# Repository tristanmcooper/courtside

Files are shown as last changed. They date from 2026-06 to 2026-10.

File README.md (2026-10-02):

# Courtside — Multi-Modal Beach Volleyball Performance Sensing

> An end-to-end personal-analytics instrument that fuses a custom ESP32 courtside
> sensor node, wearable recovery data, and per-session self-report to explain
> day-to-day beach volleyball performance for a single athlete.

**Live demo → https://courtside-yr2r.onrender.com**
*(free tier — the first load cold-starts in ~30–60s; the people/relationships shown are synthetic demo data.)*

**📄 Full write-up → [Courtside_Final_Report.pdf](Courtside_Final_Report.pdf)**

Built solo for **ECE 284 — Hardware Sensing for Digital Health**, UC San Diego.

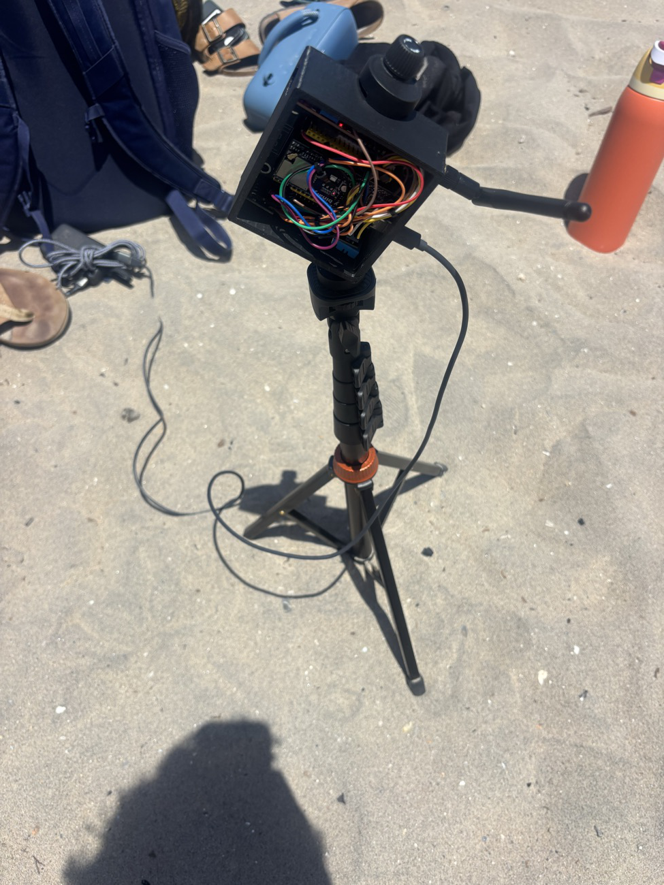
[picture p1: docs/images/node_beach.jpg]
Courtside node on the beach


## What it does

Three independent streams are captured courtside and time-aligned into one
per-session feature table:

- **Courtside node (hardware).** An ESP32-S3 logs air temperature + humidity
  (DHT11), sand-surface temperature (MLX90614 IR), and an acoustic wind proxy
  (electret mic). It posts readings over the athlete's iPhone hotspot to the
  cloud — no laptop needed on the sand.
- **Web app (FastAPI + Postgres).** A live phone dashboard for positioning the
  node, automatic ingestion of Apple Watch recovery metrics (HRV, resting HR,
  sleep) via Health Auto Export, a one-tap session log, and per-person /
  per-court / partner-vs-opponent relationship views.
- **Analysis (ML).** Per-session features → correlation screen → Lasso with
  leave-one-out CV → random forest / gradient boosting → SHAP, producing an
  interpretable ranking of which factors most explain performance.

## Screenshots

| Record a session | People & relationships |
|---|---|
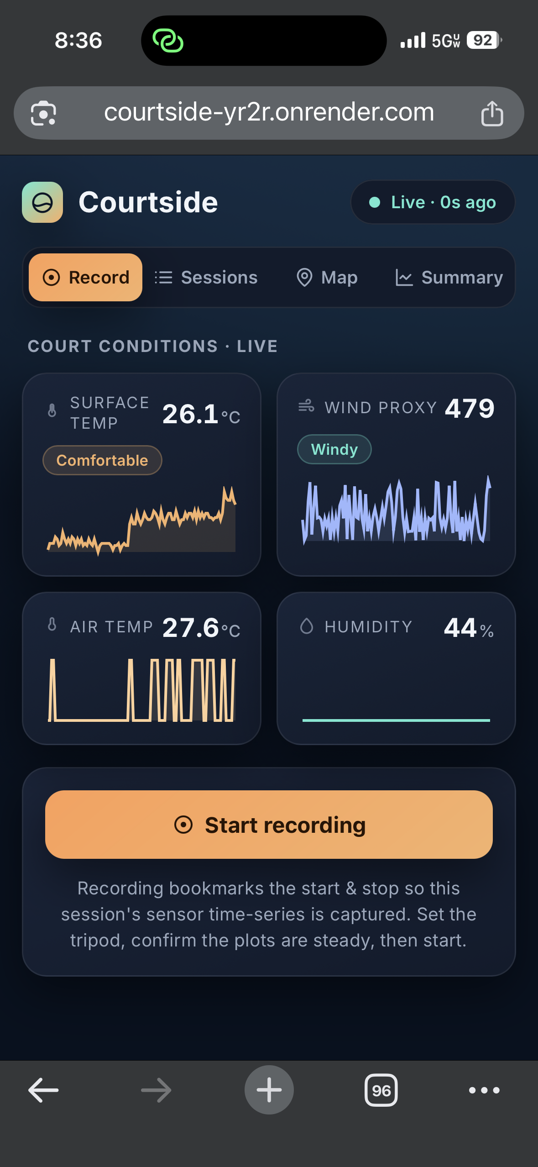
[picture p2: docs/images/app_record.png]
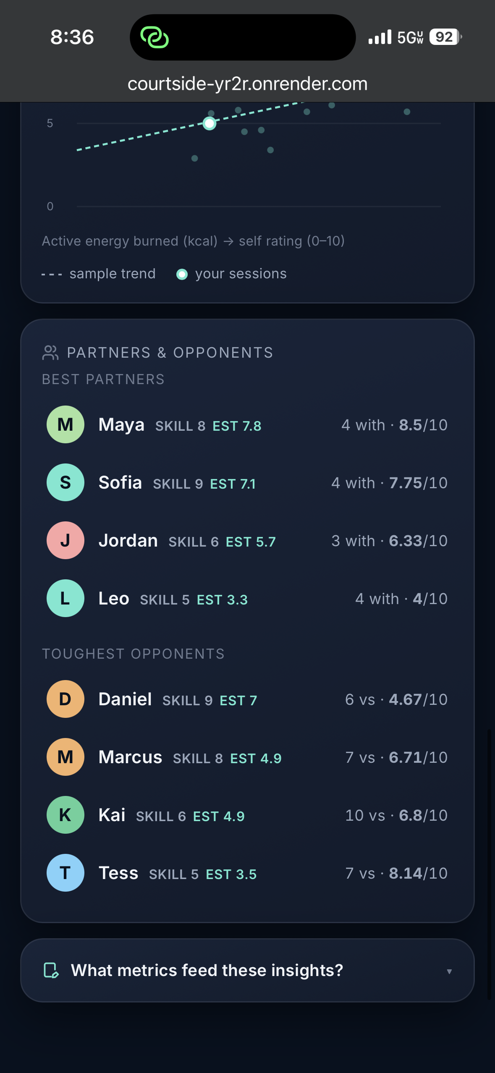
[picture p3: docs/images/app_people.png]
|  |  |
| **Court map** | **Recovery** |
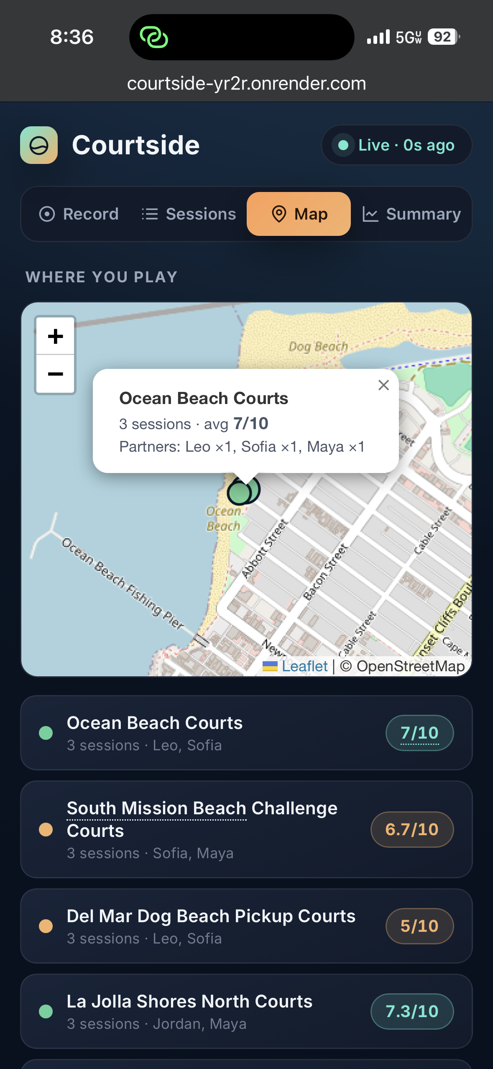
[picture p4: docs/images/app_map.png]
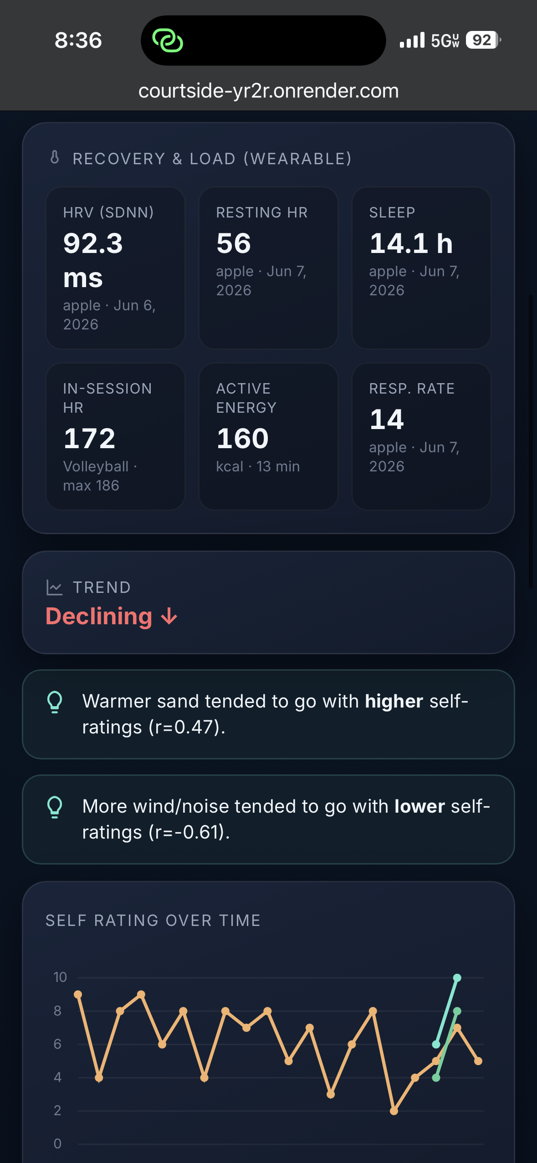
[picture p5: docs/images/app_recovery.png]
|  |  |

## Architecture

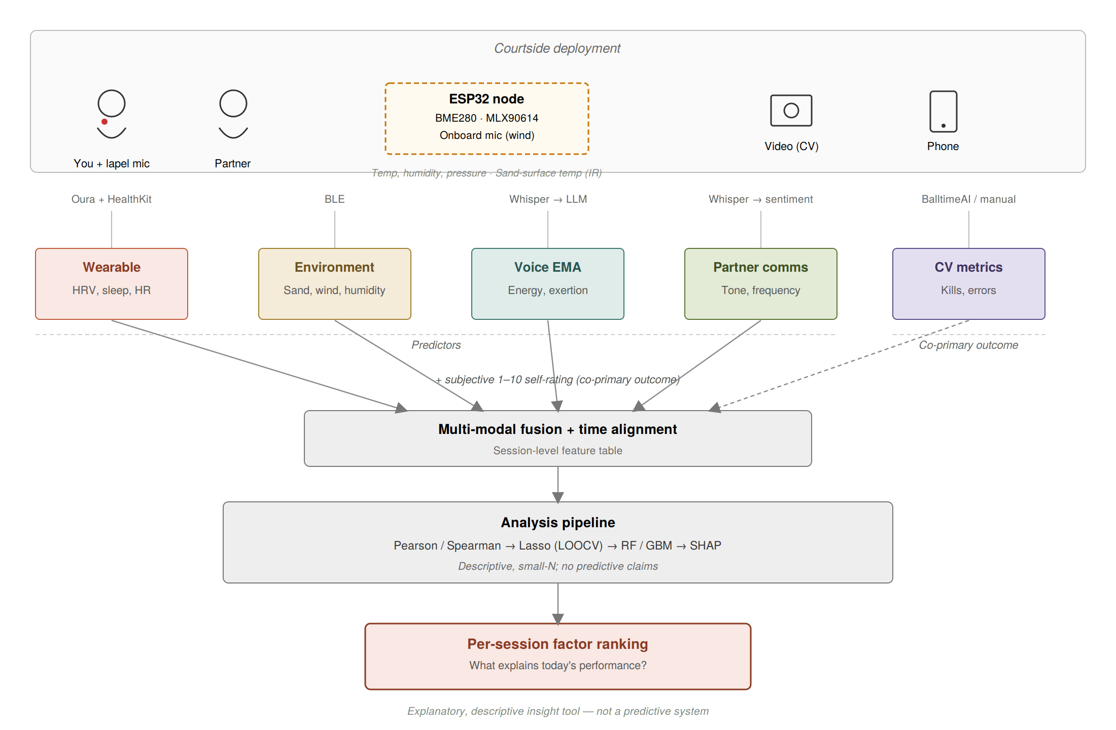
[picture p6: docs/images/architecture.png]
System architecture


## Factor ranking — the deliverable

The four-stage pipeline outputs an interpretable ranking of the environmental and
physiological factors that best explain session-to-session performance.

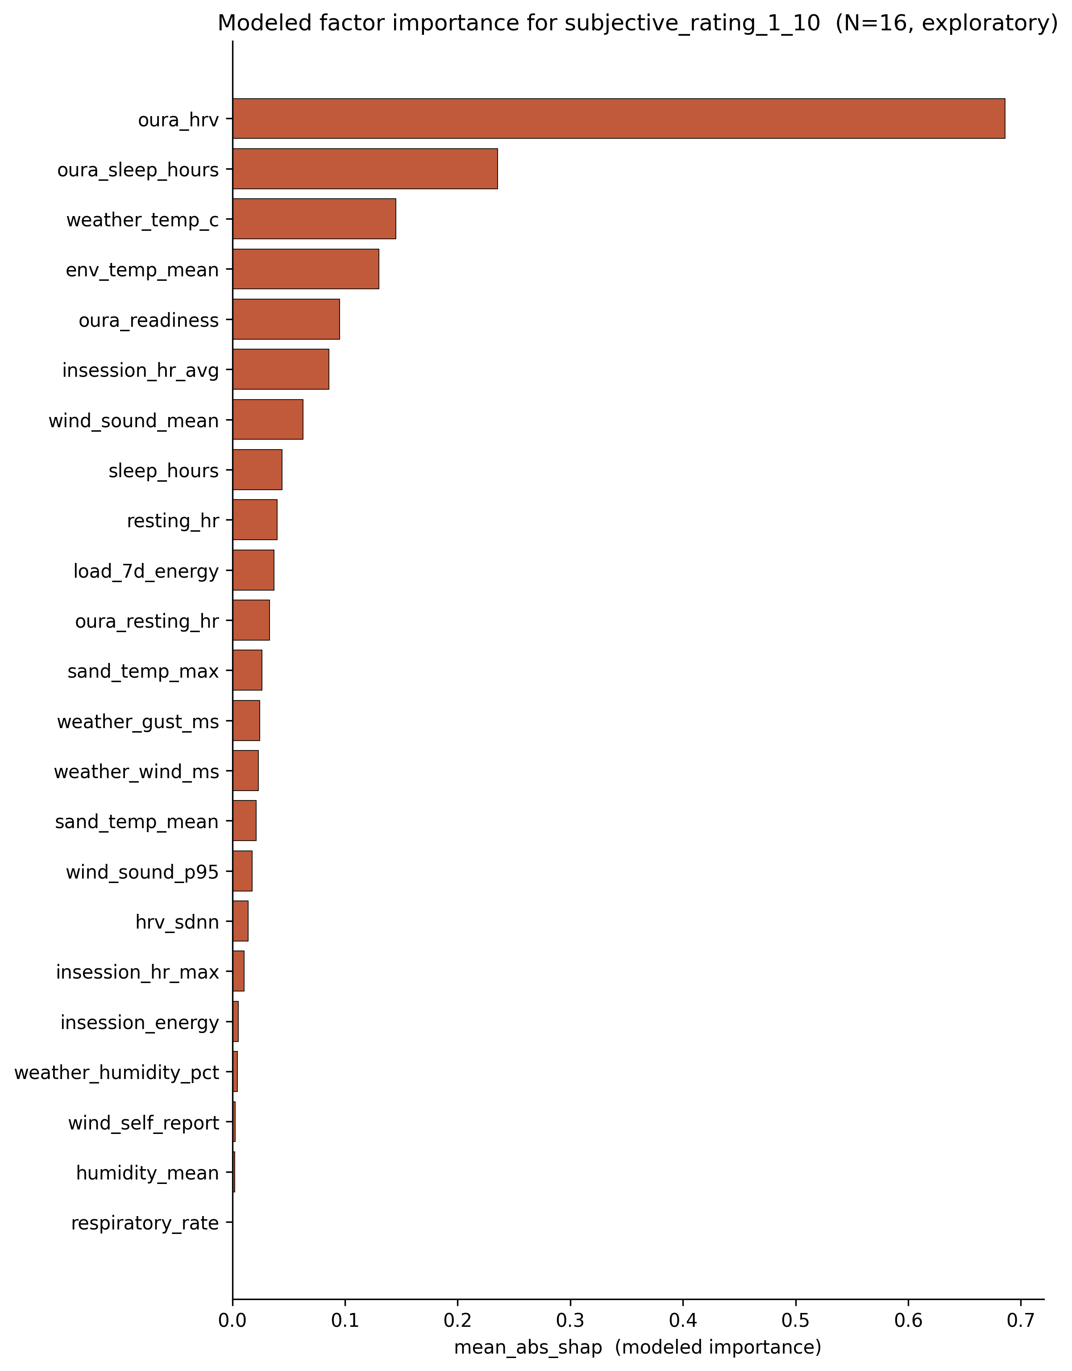
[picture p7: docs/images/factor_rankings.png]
Factor rankings


## Repo layout

```
firmware/   ESP32-S3 PlatformIO project (DHT11 + MLX90614 + mic, WiFi POST)
backend/    FastAPI app + mobile dashboard (one-click deploy via render.yaml)
scripts/    data pipeline: wearable parse, feature merge, 4-stage analysis
oura/       Oura API pull + validation plots
docs/       enclosure spec, HealthKit setup, run/defense guides, images
```

## Run it locally

```bash
# backend + dashboard
pip install -r backend/requirements.txt
uvicorn app.main:app --app-dir backend --reload        # http://127.0.0.1:8000

# firmware (PlatformIO)
cp firmware/include/secrets.h.example firmware/include/secrets.h   # fill in WiFi + backend URL
cd firmware && pio run -t upload && pio device monitor -b 115200

# analysis
pip install -r requirements.txt
python scripts/build_features.py && python scripts/analysis.py
```

Secrets (`.env`, `firmware/include/secrets.h`) are gitignored — copy the matching
`.example` files and fill in your own. Deploy to the cloud with the included
`render.yaml` (Render Blueprint → provisions the web service + Postgres).

## Notes & scope

- **N = 1 pilot.** Results are descriptive, not statistically powered; small-N is
  handled with LOOCV + regularization and reported honestly.
- **Demo data is synthetic** (`scripts/seed_demo.py`) — the partners, opponents,
  and relationship signals in the live demo exist to exercise the UI, not to
  describe real people.
- **Privacy.** Raw personal biometrics are kept out of this repo by design;
  regional weather (Open-Meteo) is used only as a coarse baseline against the
  node's court-level microclimate measurements.

## License

[MIT](LICENSE)

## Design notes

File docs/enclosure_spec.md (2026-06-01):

# Courtside Node — Enclosure Spec (for CAD)

A 3D-printed housing for a beach-volleyball courtside sensor node. It mounts on a
camera/phone tripod and holds a microcontroller + 3 environmental sensors + a
WiFi antenna. Used outdoors on sand in direct sun.

---

## Components to enclose

| # | Part | Function | Nominal size (CONFIRM) | Notes for housing |
|---|---|---|---|---|
| 1 | ESP32-S3 dev board ("Lonely Binary Gold") | brain + WiFi | ~70 × 26 × 6 mm (board); headers add ~10 mm height | USB-C on one short end must be accessible |
| 2 | **DHT11** module (blue) | air temp / humidity | ~22 × 28 mm board, sensor ~12 × 6 mm | blue sensor face must see open air; vented + shaded |
| 3 | MLX90614 IR thermometer (GY-906) | sand surface temp | ~13 × 17 mm board; metal can ~9 mm Ø, ~6 mm tall | **needs an open hole aimed down at sand** |
| 4 | Electret mic module | sound / wind proxy | ~10–15 × 15–33 mm (measure) | needs a port + foam windscreen |
| 5 | External WiFi antenna | range | flexible adhesive strip *or* SMA rod + pigtail | mount on outer/upper wall, away from metal |
| 6 | (Power) USB-C power bank | power | external | NOT enclosed — connects by USB-C cable |

Wiring is currently jumper wires; assume a small protoboard (~50 × 70 mm) or the
breadboard will sit at the bottom of the housing. Leave room + cable slack.

---

## Functional requirements (priority order)

### 1. Tripod mount — MOST IMPORTANT
- The tripod (VIMOSE 66") uses a standard **1/4"-20 UNC** screw (the male stud).
- The housing **base needs a 1/4"-20 female socket** to screw down onto it.
- **Do not print bare threads — they strip.** Use a **brass heat-set threaded
  insert (1/4"-20)** or a captured/recessed 1/4"-20 hex nut in a boss.
- Base should be flat and stable; ~6–8 mm thread engagement depth.

### 2. IR sensor aimed at the sand (MLX90614)
- The IR sensor reads surface temp by *line of sight*. **Plastic blocks IR — there
  must be an OPEN hole in front of it (no window/lens).**
- Because the node sits up on a tripod, the IR must point **down and out toward the
  sand at an angle** (e.g., a port on a lower / angled face).
- Make it **aim-able**: mount the MLX on a small adjustable bracket (tilt) or give
  2–3 alternate mounting positions, so Tristan can point it at the sand patch.
- Standard MLX90614 sees a ~90° cone — keep that cone unobstructed.

### 3. Mic / wind port
- The mic is the node's **only** wind sensor (no anemometer), used as a *qualitative*
  acoustic wind proxy — so the **foam windscreen is important**: it cuts direct-gust
  clipping so the signal tracks turbulence instead of pegging.
- A small **side port with a foam windscreen** (also a sand/spray shield, lets air in).
- A mic is *not* aimed like a directional sensor — wind noise is turbulence over the
  port, so exposure + the foam shield matter more than orientation.
- If adjustability is wanted, mount the mic on a rotatable plug.
- (The proxy is validated in software against self-reported wind + an Open-Meteo
  regional reference, not against an onboard anemometer.)

### 4. Temp/humidity chamber — must be vented + shaded
- A sealed sunlit box reads **falsely hot/dry**. The temp/humidity sensor needs a
  **vented, shaded sub-chamber** (radiation-shield / "Stevenson screen" idea):
  louvered vents on a **shaded** face (e.g., underside), airflow but no direct sun.
- This is why the whole housing should be **light/white** colored.

### 5. WiFi antenna
- Mount on an **outer or upper wall, away from the board and other metal** (metal
  shadows WiFi).
- If **SMA rod**: a ~6.5 mm bulkhead hole for the SMA connector.
- If **flexible adhesive antenna**: a flat exterior patch to stick it + a small
  slot to route the thin coax (U.FL) out from the board.

### 6. USB-C access
- A side cutout (~12 × 8 mm, position TBD by board) aligned with the ESP32's USB-C
  port, for power (power bank) and re-flashing without opening the case.

### 7. Access + assembly
- A **removable lid** (snap-fit or 4 screws) to get at the electronics.
- Internal **screw bosses or a slotted rail** so sensors can be repositioned.
- Cable strain-relief for the antenna coax and USB cable.

---

## Material & environment
- **PETG or ASA**, *not PLA* — PLA sags in beach heat / direct sun. ASA is best for
  UV; PETG is fine and easier to print.
- **Light/white color** — reflects sun, keeps the temp sensor honest.
- Sand-resistant (not waterproof): vents face down, no large top openings.
- Keep it compact but leave ~10–15 mm clearance around the board for cables/heat.

---

## Summary for a quick start
A light-colored vented box that **screws onto a 1/4"-20 tripod stud**, with: an
**open downward-angled hole** for the IR (sand) sensor, a **foam-screened side
port** for the mic, a **louvered shaded vent** for the temp/humidity sensor, an
**antenna mount** on an outer wall, and a **USB-C cutout**. Removable lid, internal
adjustable sensor mounts. Print in PETG/ASA, white.

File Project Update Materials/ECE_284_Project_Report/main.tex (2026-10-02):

\documentclass[sigconf,nonacm]{acmart}

% ACM Large 2-column per ECE 284 spec. If acmart is unavailable, replace with
% \documentclass[10pt,twocolumn]{article} and delete the \affiliation/\email block.

\settopmatter{printacmref=false, printfolios=true}
\renewcommand\footnotetextcopyrightpermission[1]{}
\pagestyle{plain}

\usepackage{graphicx}
\usepackage{booktabs}
\usepackage{amssymb}   % \checkmark
\usepackage{tikz}      % labeled hardware callouts
\usepackage{hyperref}

\title{Courtside: A Deployed Multi-Modal Sensing Instrument for Contextualizing Beach Volleyball Performance}

\author{Tristan Cooper}
\affiliation{%
  \institution{UC San Diego}
  \city{La Jolla}
  \state{CA}
  \country{USA}
}
\email{tmcooper@ucsd.edu}

\begin{document}

\begin{abstract}
Beach volleyball athletes experience large day-to-day performance variability that no single tool explains: wearables report overnight recovery without same-day context, weather services miss court-level microclimate (wind in particular), and mid-match self-report is impractical. We designed, built, and \emph{deployed} \textbf{Courtside}, a multi-modal sensing instrument that fuses six streams---a custom courtside environmental node (ESP32-S3 with a DHT11 air temperature/humidity sensor, an MLX90614 infrared sand-surface thermometer, and an electret-microphone wind/audio proxy), wearable recovery physiology (Apple Watch via automated HealthKit export and Oura Ring via API), wearable workout intensity (in-session and prior-load), coarse regional weather (Open-Meteo), per-session subjective/objective performance logging, and the \emph{spatial} and \emph{relational} context of each session (which court, and which partners and opponents). The node streams over the athlete's phone hotspot to a cloud backend (FastAPI + PostgreSQL on Render) and a mobile web app that runs live setup, session recording, evaluation entry, an interactive court map, and partner/opponent ``personas'' with statistically-guarded relationship signals. A four-stage factor-ranking analysis (correlation $\rightarrow$ sparse linear selection $\rightarrow$ tree ensembles $\rightarrow$ SHAP) closes the loop. We validate the instrument end-to-end on a single-athlete pilot---including a 20-respondent player survey that shaped the feature set and a live beach day capturing sand-surface temperatures near 40\,$^\circ$C against $\sim$26\,$^\circ$C air, alongside synchronized Apple Watch recovery and in-session heart rate. We frame the contribution honestly: the value is the \emph{working instrument}, the user-needs study, and the gap it fills---not statistical claims, which the small real sample ($N{=}2$ fully-instrumented sessions) cannot support. Where analytics need scale, we demonstrate them on clearly-labeled sample data \emph{built around those two real sessions} to show the output the instrument produces.

\smallskip
\noindent\emph{Artifact.} The complete system---firmware, backend, web app, and analysis---is open-source at \url{https://github.com/tristanmcooper/courtside}, with a live demo at \url{https://courtside-yr2r.onrender.com}.
\end{abstract}

\maketitle

\begin{figure}[t]
    \centering
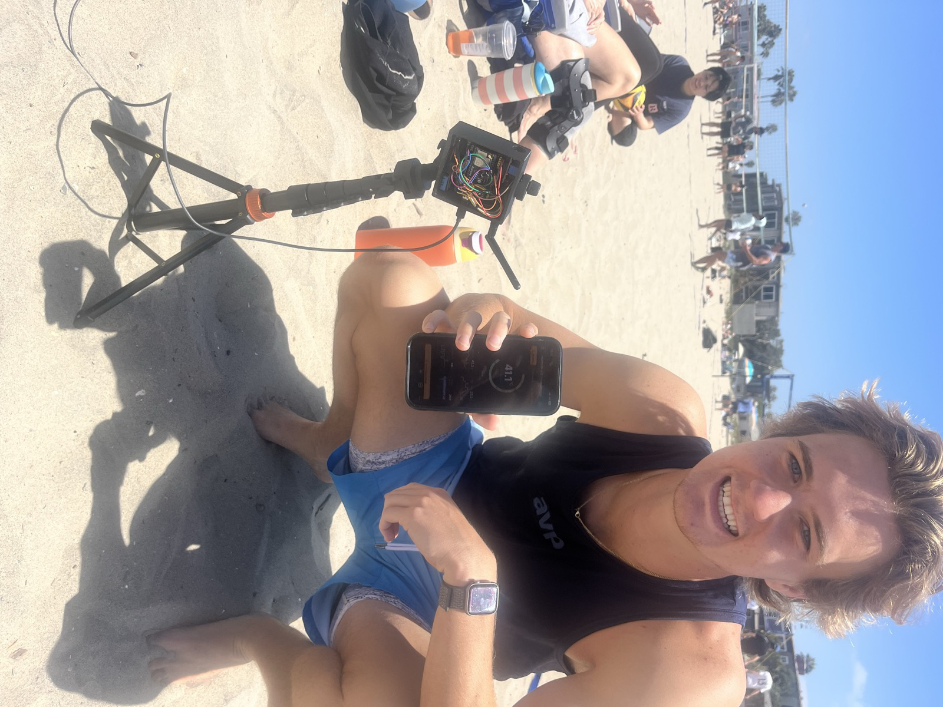
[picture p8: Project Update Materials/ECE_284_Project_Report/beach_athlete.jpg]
    
    \caption{The whole system in the field. The courtside node runs untethered on a tripod (battery-powered, streaming over the phone's hotspot); the athlete reads live conditions in the web app while an Apple Watch supplies recovery and in-session heart rate. Everything in this photo is a working part of the deployed instrument.}
    \label{fig:teaser}
\end{figure}

%===================================================================
\section{Motivation}
%===================================================================
I began this project from my own experience. After starting to play beach volleyball at an elite collegiate level, I found it genuinely hard to tell whether I was improving, to discriminate the quality of one training session from another, and to know \emph{what} actually drove a good or bad day. Playing with partners of all ages and skill levels, and across very different courts, made clear this is a common problem, not just mine: athletes know some days they play well and others they do not, but isolating \emph{why} is hard because recovery, environment, game context, and mindset all interact, while existing tools each measure one dimension in isolation---or none at all.

\textbf{Three blind spots.} \emph{(1) Wearables} (WHOOP, Oura, Garmin, Apple Watch) report readiness from overnight HRV and sleep but ignore same-day environmental load and subjective state. \emph{(2) Weather apps} report city-grid conditions and miss court-level microclimate: wind is reshaped by surrounding terrain---the Muir courts on the UCSD campus are ringed by buildings that create a swirling environment which reshapes serve-receive in a way no nearby weather station could capture---and sand-surface temperature varies with grain size, moisture, and direct sun in ways ambient air temperature cannot. \emph{(3) Self-evaluation} is limited to what an athlete can remember and to their own pattern recognition; it carries heavy confounds (partner, opponent) and places the entire measurement burden on the athlete mid-competition, when compliance collapses.

\textbf{The gap.} No system fuses \emph{recovery $+$ environment $+$ subjective state $+$ performance}---together with \emph{where} and \emph{with whom} a session happened---for an individual beach volleyball athlete. Each stream exists in isolation.

\textbf{Who benefits.} The immediate end user is the recreational or collegiate beach athlete who today has no way to contextualize why a session felt the way it did. The broader health relevance is exertional-heat safety: beach volleyball is outdoors with no climate control, and early warning for heat strain requires exactly the physiological--environmental--subjective fusion this instrument produces. A sand-surface temperature near 40\,$^\circ$C---measured in our pilot---is well above the $\sim$26\,$^\circ$C air temperature a weather app would report for the same moment.

%===================================================================
\section{Related Work}
%===================================================================
\textbf{Commercial wearable recovery.} WHOOP, Oura, and Garmin produce daily readiness scores from overnight biometrics; validation studies show reasonable resting HRV and sleep accuracy, but these scores are not contextualized against same-day environment or subjective state. Apple Watch exposes HRV (SDNN) and in-workout heart rate via HealthKit. Courtside treats these as one input among several rather than the whole picture.

\textbf{Environmental monitoring in sport.} The FIVB enforces WBGT-based heat protocols at professional events and the NATA publishes heat-illness position statements~\cite{casa2015}, but these rely on coarse point measurements and are largely absent from recreational and collegiate settings. We bring a low-cost court-level environmental node to exactly that gap.

\textbf{Ecological momentary assessment (EMA).} EMA is well-validated in sport and behavioral health~\cite{shiffman2008}; voice-based capture with modern ASR has been proposed to lower burden. We scope voice EMA out (Section~\ref{sec:discussion}) in favor of a low-burden structured post-session form.

\textbf{Wearables in beach volleyball.} Prior work targets different questions: Marzano-Felisatti et al.\ (2024)~\cite{marzano2024} applied an electronic performance-tracking system to quantify physical-conditional performance of young male players, and the University of Sussex ``Wearables in Beach Volleyball'' project~\cite{sussex} investigates IMU-based match load and event detection. Both focus on movement classification and training-load quantification from a single modality. Neither fuses physiological recovery, environmental context, spatial/relational context, and subjective experience into a joint per-session analysis.

\textbf{Gap.} No published system performs this multi-modal, individual-athlete fusion for beach volleyball.

%===================================================================
\section{Project Aim}
%===================================================================
\textbf{Primary aim.} Build a working instrument that captures synchronized multi-modal sessions for a single beach volleyball athlete and runs a per-session factor-ranking analysis identifying which contextual streams plausibly explain performance variation. \textbf{End user:} the athlete; output is personally actionable, not a clinical or coaching product. \textbf{Non-goals:} not a deployable predictive model, not cross-sport, not clinically validated.

\textbf{Following up on the proposal and update.} Table~\ref{tab:scope} maps what was proposed and updated against what was delivered, with honest substitutions. The proposal committed to Oura + Apple Watch + a BME280 environmental node + a subjective rating + 6--10 sessions, with voice EMA and computer-vision (CV) kill/error extraction as stretch goals. The update reported the survey, bench-validated sensing, and an MLX90614 in transit. For the final system, the environmental sensing, wearable ingestion, web app, and analysis pipeline were all delivered and deployed; the BME280 was substituted with a DHT11; the app additionally grew spatial (court map) and relational (partner/opponent personas) dimensions that were not in the proposal; and voice EMA and CV were de-scoped to keep the core instrument robust. The dominant gap versus the proposal is session count: collegiate season timing and hardware lead times compressed real data collection.

\begin{table}[t]
\caption{Proposed/updated vs.\ delivered. \checkmark\ delivered, $\sim$ substituted, $+$ added beyond proposal, $\times$ de-scoped.}
\label{tab:scope}
\small
\begin{tabular}{@{}lll@{}}
\toprule
Component & Proposed/Update & Final \\
\midrule
Wearable recovery (Oura) & API pull & \checkmark\ API \\
Wearable (Apple Watch) & HealthKit & \checkmark\ auto HealthKit export \\
In-session HR / workouts & stretch & \checkmark\ parsed (avg/max/energy) \\
Air temp / humidity & BME280 & $\sim$ DHT11 \\
Sand-surface temp (IR) & MLX90614 & \checkmark\ MLX90614 \\
Wind proxy (acoustic) & mic & \checkmark\ mic (qualitative) \\
Regional weather context & --- & $+$ Open-Meteo \\
Web app / live capture & local logging & \checkmark\ cloud app + recording \\
Court map (spatial) & --- & $+$ interactive map \\
Partner/opponent personas & --- & $+$ relational analytics \\
Subjective outcome & 1--10 rating & \checkmark\ rating (+ peer/coach) \\
4-stage analysis & planned & \checkmark\ implemented \\
Voice EMA & stretch & $\times$ de-scoped \\
CV kill/error outcome & stretch & $\times$ de-scoped \\
$\geq$6 full-stream sessions & target & $\times$ small $N$ (limitation) \\
\bottomrule
\end{tabular}
\end{table}

%===================================================================
\section{System Architecture and Implementation}
%===================================================================
The engineering is the heart of this project, so we describe the deployed system in detail. Figure~\ref{fig:arch} shows the end-to-end data path; it is a live system, not a mockup.

\begin{figure*}[t]
    \centering
    
    \caption{System architecture. The courtside node streams sensor readings over the athlete's phone hotspot to a cloud backend; the Apple Watch and Oura push recovery and workout data to the same backend; the athlete logs subjective/objective outcomes from the mobile web app. All streams are time-aligned into one per-session feature table feeding the four-stage factor-ranking analysis.}
    \label{fig:arch}
\end{figure*}

\subsection{Courtside Environmental Node}
An ESP32-S3 microcontroller (Fig.~\ref{fig:internal}) reads three channels at 1\,Hz: a \textbf{DHT11} (air temperature and humidity, one-wire digital); an \textbf{MLX90614} non-contact infrared thermometer (sand-surface temperature, I\textsuperscript{2}C address 0x5A) that senses emitted infrared and therefore requires no contact and no exposed window (plastic blocks infrared, so the enclosure leaves an open aperture aimed at the sand); and an analog \textbf{electret microphone} whose 50\,ms peak-to-peak amplitude serves as a low-cost wind/audio proxy. A deliberate hardware detail: the microphone is read on an \emph{ADC1} pin, because the ESP32's ADC2 is commandeered by the WiFi radio---reading the mic on ADC2 would silently fail whenever the radio is active.

The electronics are housed in a custom 3D-printed enclosure designed in Fusion~360 (Fig.~\ref{fig:cad}) with a louvered vent for the air sensor, an open IR aperture, a foam-screened microphone port, and a 1/4-20 thread so the node mounts on a standard camera tripod and can be raised, leveled, and rotated on site. The node runs untethered from a USB power bank. Figure~\ref{fig:internal} shows the internals: the printed lid (left) carries custom standoffs and cutouts that seat each sensor at its aperture, while the body (right) holds the board, the tripod boss, and the sensor harness.

\begin{figure}[t]
    \centering
    \begin{tikzpicture}
      \node[anchor=south west,inner sep=0] (img) at (0,0)
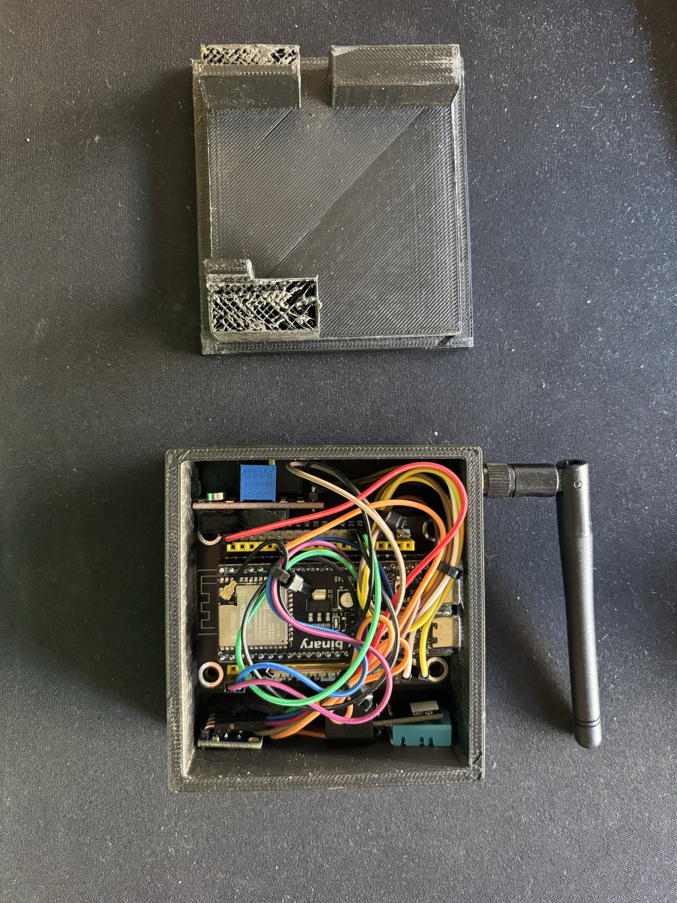
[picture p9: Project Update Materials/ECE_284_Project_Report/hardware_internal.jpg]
        {};
      \begin{scope}[x={(img.south east)},y={(img.north west)}]
        \tikzset{cal/.style={circle,fill=red!85!black,draw=white,line width=0.3pt,
          text=white,font=\scriptsize\bfseries,inner sep=0.7pt,minimum size=3.6mm}}
        \node[cal] at (0.64,0.90) {1};
        \node[cal] at (0.80,0.71) {2};
        \node[cal] at (0.865,0.61) {3};
        \node[cal] at (0.865,0.30) {4};
        \node[cal] at (0.52,0.30) {5};
        \node[cal] at (0.20,0.55) {6};
      \end{scope}
    \end{tikzpicture}
    \caption{Inside the node. \textbf{1} ESP32-S3 antenna; \textbf{2} USB-C power; \textbf{3} DHT11 air temperature/humidity (top-right); \textbf{4} MLX90614 infrared sand-surface sensor (bottom-right); \textbf{5} electret microphone wind/audio proxy (bottom-left); \textbf{6} 3D-printed lid with custom cutouts and standoffs that seat each sensor. (Callout positions per the build layout.)}
    \label{fig:internal}
\end{figure}

\begin{figure}[t]
    \centering
    \hfill
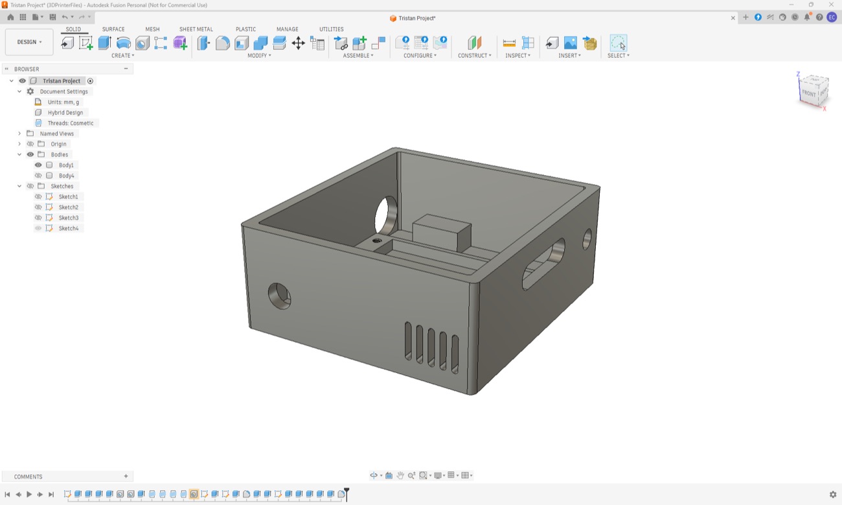
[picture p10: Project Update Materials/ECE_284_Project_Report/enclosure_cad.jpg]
    
    \caption{Left: the node deployed courtside on sand, tripod-mounted and battery-powered. Right: the enclosure CAD (Fusion~360)---louvered air-sensor vent, open IR aperture, and tripod mount.}
    \label{fig:cad}
\end{figure}

\subsection{Firmware and Connectivity}
The firmware (C++/Arduino, built in PlatformIO) connects to the athlete's iPhone Personal Hotspot as a WiFi station and HTTP-POSTs each reading as JSON to the backend, authenticated by a node key. It includes a boot-time I\textsuperscript{2}C bus scan that prints discovered addresses for field debugging, and a serial-CSV fallback so the node still logs if connectivity drops. Because the ESP32-S3 is 2.4\,GHz only, the hotspot is set to maximize-compatibility mode. This wireless-over-hotspot path is what lets the system run on a beach with no laptop and no SD card.

\subsection{Cloud Backend and Data Model}
A FastAPI service backed by PostgreSQL is deployed on Render and auto-deploys on each push. It exposes ingest endpoints (court readings, health, workouts), a session CRUD and recording API, people/personas, an aggregated court endpoint for the map, a relationship-signals endpoint, and a full export for the offline pipeline. The schema separates concerns into \texttt{court\_readings}, \texttt{health\_daily} (one row per day$\times$source), \texttt{sessions}, \texttt{workouts}, and---added for the relational features---\texttt{people} and a \texttt{session\_people} link table. Every wearable payload is retained losslessly in a raw JSON column so new signals can be promoted later without re-collection, and a lightweight auto-migration adds new model columns to the live database on deploy.

\subsection{Mobile Web App}
The app (vanilla JS, no build step, installable as a phone web app) is the instrument's user surface. Figure~\ref{fig:applive} shows it running live over cellular on the first instrumented beach day. It provides a \emph{live setup view} with real-time per-sensor plots and a heuristic check (it warns when the IR reading $\approx$ air temperature, indicating the sensor is not yet aimed at the sand); a \emph{recording} flow that bookmarks each session's start/stop so its sensor time-series window is captured; and an \emph{evaluation} form capturing the subjective 1--10 self-rating, optional peer/coach ratings, felt-wind, kills/errors, player state (energy, soreness, mental, warm-up, food timing), partner/opponents, location, notes, and geolocation.

\begin{figure*}[t]
    \centering
    \hfill
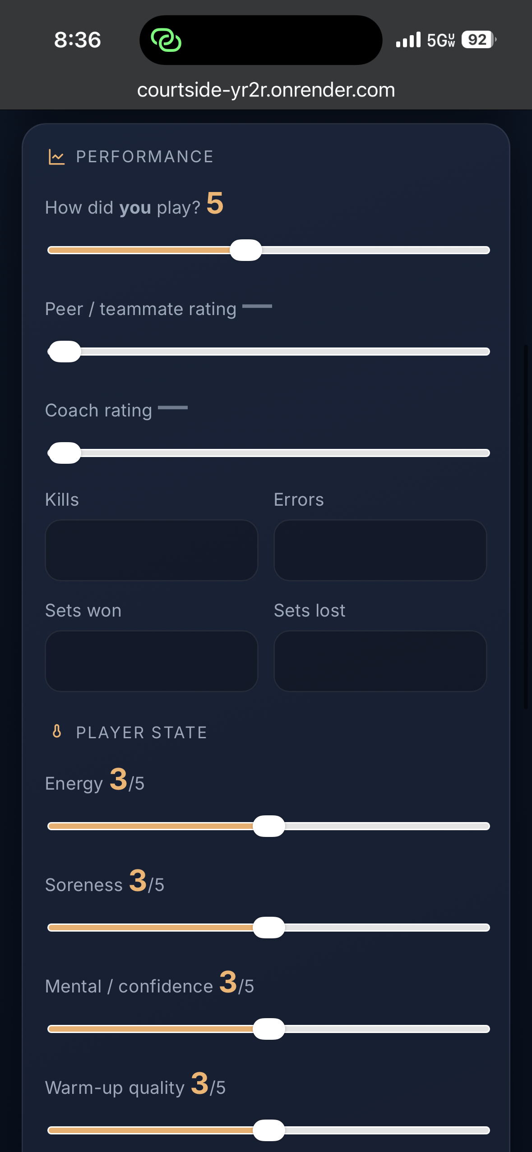
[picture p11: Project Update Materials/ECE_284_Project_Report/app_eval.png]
    \hfill
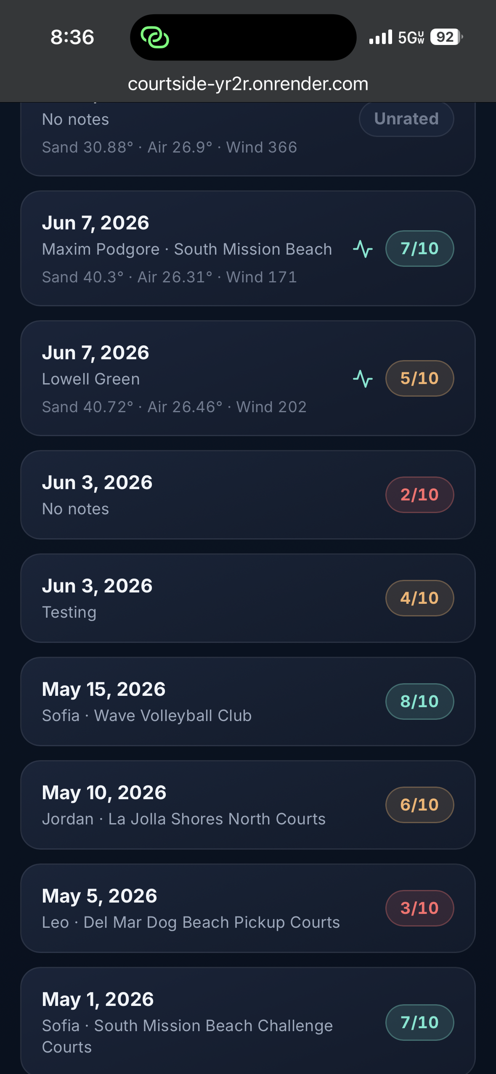
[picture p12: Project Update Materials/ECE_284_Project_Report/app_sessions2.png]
    
    \caption{The deployed app on the athlete's phone over 5G, with four tabs (Record, Sessions, Map, Summary). Left: the live setup view (``Live $\cdot$ 0s ago'') with balanced per-sensor cards and a ``Comfortable/Windy'' interpretation. Center: the post-session evaluation form, including the survey-driven player-state sliders (energy, soreness, mental, warm-up). Right: the session list---the June entries are \textbf{real pilot sessions} (sand 40.3--40.7\,$^\circ$C against $\sim$26\,$^\circ$C air, workout-paired), interleaved with sample sessions used for demonstration.}
    \label{fig:applive}
\end{figure*}

\subsection{Wearable and Weather Ingestion}
Apple Watch data syncs automatically via the Health Auto Export app's REST automation, posting HRV (SDNN), resting heart rate, sleep, respiratory rate, and \emph{workouts} to the backend, upserted by date. Oura is pulled via its v2 API as a \emph{second} recovery source, enabling cross-validation (Apple SDNN vs.\ Oura RMSSD). Open-Meteo~\cite{openmeteo} supplies coarse regional weather (wind, gust, temperature, humidity), kept clearly separate from on-court sensor readings---context, not mixed-in measurement.

\subsection{Spatial Context: the Court Map}
Because the app already captures geolocation, sessions are grouped by court and plotted on an interactive map (Fig.~\ref{fig:map}). Each marker is colored by the athlete's average rating there; tapping a court reveals its session count, average rating, average node-measured wind and surface temperature, and who the athlete has played with at that court. This makes ``I play better at La Jolla Shores than at Ocean Beach'' a queryable, visual fact rather than a vague impression.

\begin{figure}[t]
    \centering
    
    \caption{The Map view with a court tapped open: session count, average rating, and who the athlete has played with there, over markers colored by average rating. Populated mostly with \textbf{sample data} to demonstrate the feature; the pilot's real courts appear here too.}
    \label{fig:map}
\end{figure}

\subsection{Relational Context: Partner/Opponent Personas}
Beach volleyball is a 2v2 game and, candidly, a deeply relational and emotional one---who you play with and against shapes both performance and experience. Courtside therefore promotes partners and opponents from free text to first-class \emph{people} records that accrue history. For each person the app shows the athlete's average rating \emph{with} them (as partner) or \emph{against} them (as opponent), a self-rated skill, and an \emph{estimated} skill derived from results---a partner who consistently lifts the athlete's rating, or an opponent who consistently lowers it, reads as stronger (Fig.~\ref{fig:rel}, right).

Crucially, the app surfaces \emph{relationship signals} as notifications (Fig.~\ref{fig:rel}, left). For each person with enough sessions, it compares the athlete's ratings with versus without that person using a Welch's $t$-test (implemented in pure Python so the web service stays dependency-light), and flags notable, small-$N$-guarded effects: ``you play your best with Maya,'' or ``tough matchup against Daniel.'' This operationalizes the intuition every athlete has---``of course I played badly, I was up against the best player there''---into an explicit, evidence-weighted prompt. As with the pipeline, these analytics are shown on labeled sample data because the real pairing history is not yet large enough for inference.

\begin{figure*}[t]
    \centering
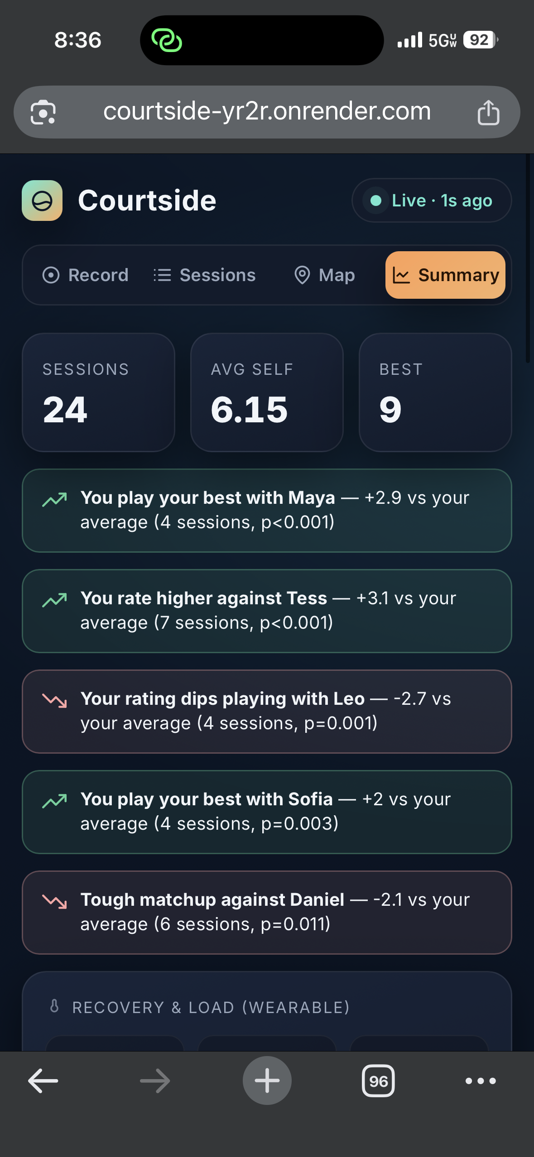
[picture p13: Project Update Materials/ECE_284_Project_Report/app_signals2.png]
    \hfill
    \hfill
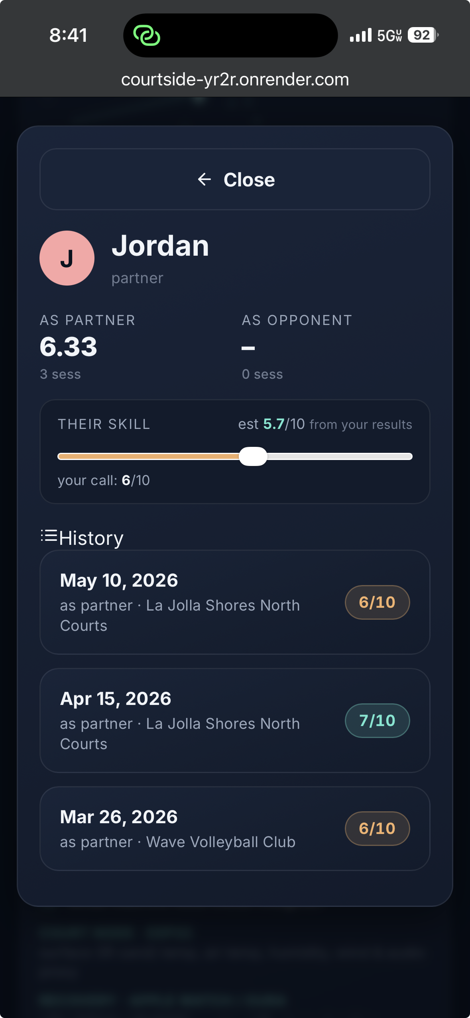
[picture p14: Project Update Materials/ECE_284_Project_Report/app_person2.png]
    
    \caption{Relational analytics (\textbf{sample data}; the pilot has only $N{=}2$ fully-instrumented real sessions, so these views are demonstrations built around the pilot's data). Left: relationship signals comparing the athlete's ratings with/without each person (Welch's $t$, small-$N$ guarded)---partner boosts and the ``tough matchup'' opponent drags. Center: partners and opponents ranked, each with a self-rated and a results-estimated skill. Right: a person view (a partner here) with as-partner/as-opponent averages and full history.}
    \label{fig:rel}
\end{figure*}

%===================================================================
\section{Design Decisions and Development History}
%===================================================================
The system arrived at its present form through a sequence of deliberate decisions; we recount them as a narrative (ordered, undated) because the \emph{reasoning} is the contribution.

\textbf{Survey before silicon.} Before investing further in hardware we ran a 20-player needs survey (Section~\ref{sec:results}) to decide what to sense. Wind ranking first is the reason the acoustic wind proxy survived and court noise and pace-of-play were dropped.

\textbf{Sensor selection and an honest substitution.} The proposal specified a BME280 (temperature, humidity, pressure). When the on-hand part proved unreliable, we substituted a DHT11 to keep air temperature and humidity working, accepting the loss of barometric pressure and lower resolution---a pragmatic trade we flag as a limitation rather than hide. The MLX90614 was chosen specifically because infrared sensing needs no ground contact and no fragile window.

\textbf{Bench-first bring-up.} Each sensor was validated on the bench before field use (Fig.~\ref{fig:bench}, Fig.~\ref{fig:smoke}), and the firmware gained an I\textsuperscript{2}C scanner so a missing sensor is diagnosable in seconds on the sand.

\textbf{The pivotal pivot: from scripts to a cloud instrument.} The original plan logged to a laptop over USB. We realized this is unusable on a beach, and re-architected around the athlete's phone: the node streams over the phone hotspot to a cloud backend, and the phone itself is the live dashboard. This single decision---no laptop, no SD card---is what makes the instrument genuinely field-usable.

\textbf{The app as the instrument, not an afterthought.} Once the data lived in the cloud, the web app became the product surface: live setup, recording windows, and evaluation entry replaced a clipboard and a spreadsheet.

\textbf{Frictionless wearable capture.} Rather than manual exports, we adopted Health Auto Export's REST automation so Apple Watch recovery and workouts arrive on their own, and kept Oura as an independent cross-check.

\textbf{Spatial and relational dimensions last.} With the core solid, we added the court map and the partner/opponent persona system---the features that most directly serve the ``relationship sport'' nature of beach volleyball---each backed by real database tables so they grow with use.

\subsection*{Fabrication}
The node was hand-built and hand-soldered (Fig.~\ref{fig:smoke}, left), with each subsystem brought up and smoke-tested individually before integration (Fig.~\ref{fig:smoke}, right shows the first working IR read).

\begin{figure}[t]
    \centering
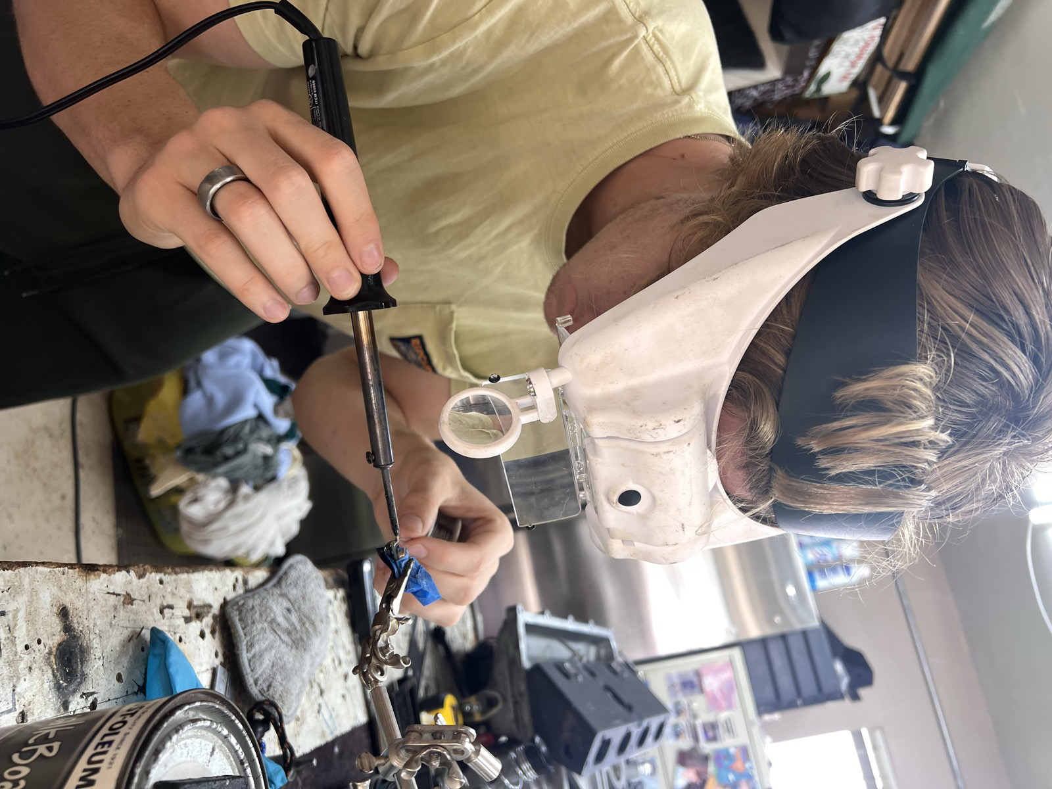
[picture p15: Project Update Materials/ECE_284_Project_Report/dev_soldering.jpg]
    \hfill
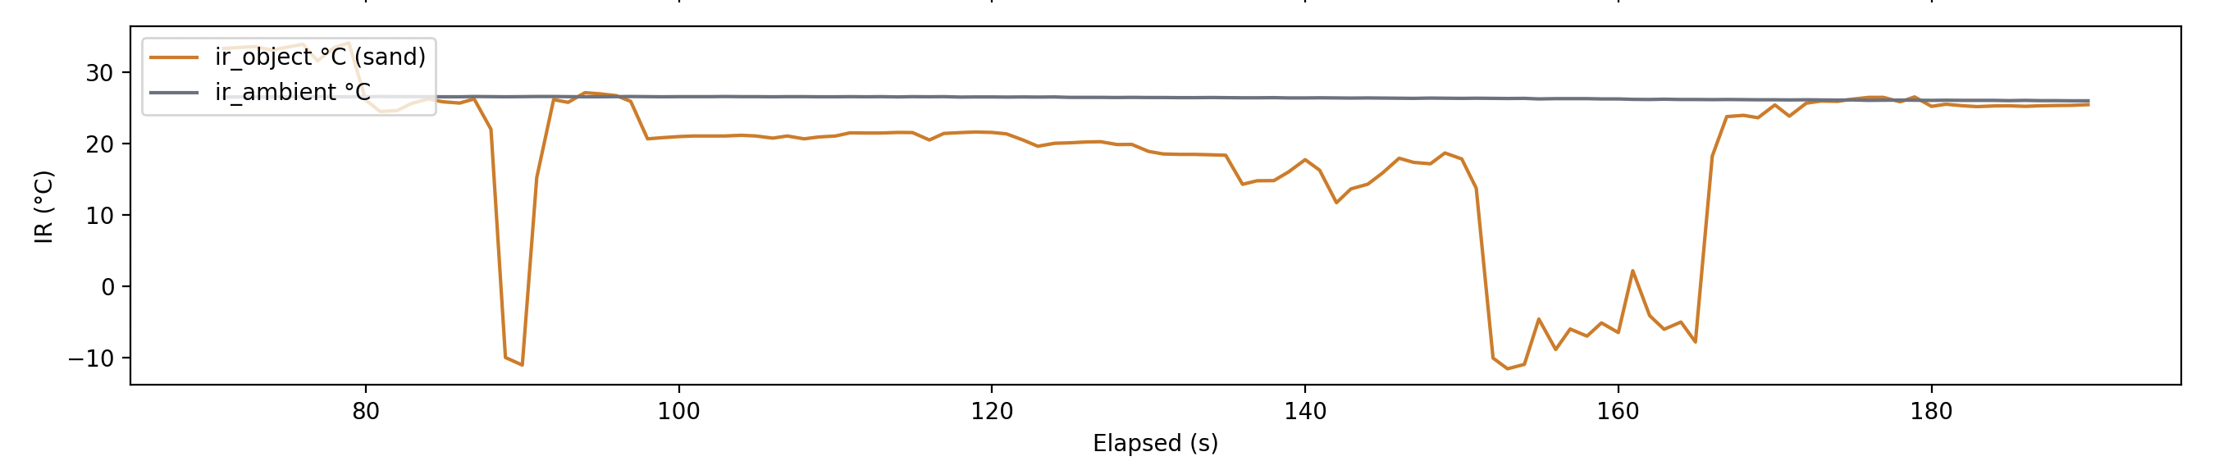
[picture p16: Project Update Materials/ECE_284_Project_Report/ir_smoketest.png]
    
    \caption{Fabrication and bring-up. Left: hand-soldering the node under a magnifier visor. Right: the first successful MLX90614 infrared read during bench bring-up.}
    \label{fig:smoke}
\end{figure}

%===================================================================
\section{Methodology}
%===================================================================
\subsection{Data Handling and Feature Engineering}
Sensor rows are stamped with server-receive time. Each logged session windows the node readings to its recording interval and aggregates them (mean/max sand and air temperature, mean humidity, mean and 95th-percentile wind-audio). Daily wearable recovery joins by date (Apple preferred, Oura fallback and cross-check). Apple Watch \emph{workouts} overlapping the session window yield in-session intensity (average/max HR, active energy); workouts in the prior seven days yield a cross-training \emph{load} feature. Regional weather is attached per session location, and partner/opponent links attach the relational context. The unit of analysis is the session---appropriate given small $N$---producing one tidy multi-modal feature row per session ($\sim$40 columns).

\subsection{Analysis Pipeline}
The analysis is exploratory and descriptive, in four small-$N$-aware stages: (1) Pearson and Spearman correlations of each feature against the subjective rating; (2) Lasso regression with leave-one-out cross-validation for sparse feature selection; (3) random-forest and gradient-boosting feature importances to capture interactions; (4) SHAP values~\cite{lundberg2017} from the gradient-boosting model for per-factor attribution. We additionally compute leave-one-session-out top-3 stability. The pipeline (scikit-learn~\cite{sklearn}) degrades gracefully: below a sample threshold it emits correlations plus an explicit caveat rather than fabricating a model. No $p$-values are reported as confirmatory, and no model is released for deployment.

\subsection{Relationship Statistics}
For the relational signals, each person's with-set and without-set of ratings are compared with a two-sided Welch's $t$-test (unequal variance), with the $p$-value computed from the regularized incomplete beta function in pure Python. Signals fire only with $\geq$3 sessions for the person, an effect of $\geq$0.8 rating points, and $p<0.1$---thresholds chosen to be informative on small samples while explicitly labeled preliminary.

\subsection{Evaluation Criteria}
Because the output is a per-session explanation rather than a prediction, standard ML metrics do not apply. We evaluate on engineering criteria: \textbf{data completeness} (fraction of sessions with all streams captured), \textbf{time alignment} (streams aligned to server-receive time and the recording window), \textbf{sensor responsiveness} (bench validation per channel), and \textbf{ranking stability / face validity} (leave-one-session-out stability and comparison of top factors to the athlete's recollection)---the latter two meaningful only once $N$ is sufficient.

%===================================================================
\section{Results}
\label{sec:results}
%===================================================================
\subsection{User-Need Validation (N=20)}
Before further hardware investment we surveyed 20 players (UCSD men's/women's beach teams plus recreational, club, NCAA, and Open/AVP players) to validate need and prioritize features (Fig.~\ref{fig:survey}). \textbf{Wind ranked first} (4.05/5), validating the decision to prioritize wind sensing; recovery/tiredness, mental state, partner identity, and partner communication completed the top five; court noise, location, and pace of play ranked lowest and were dropped from the feature plan. Open responses repeatedly raised \emph{food timing}, \emph{soreness}, and \emph{warm-up quality}, motivating the lightweight player-state inputs. Across the cohort, 85\% expressed positive interest, with qualified interest centered on wearable integration and minimal in-session burden.

\begin{figure}[t]
    \centering
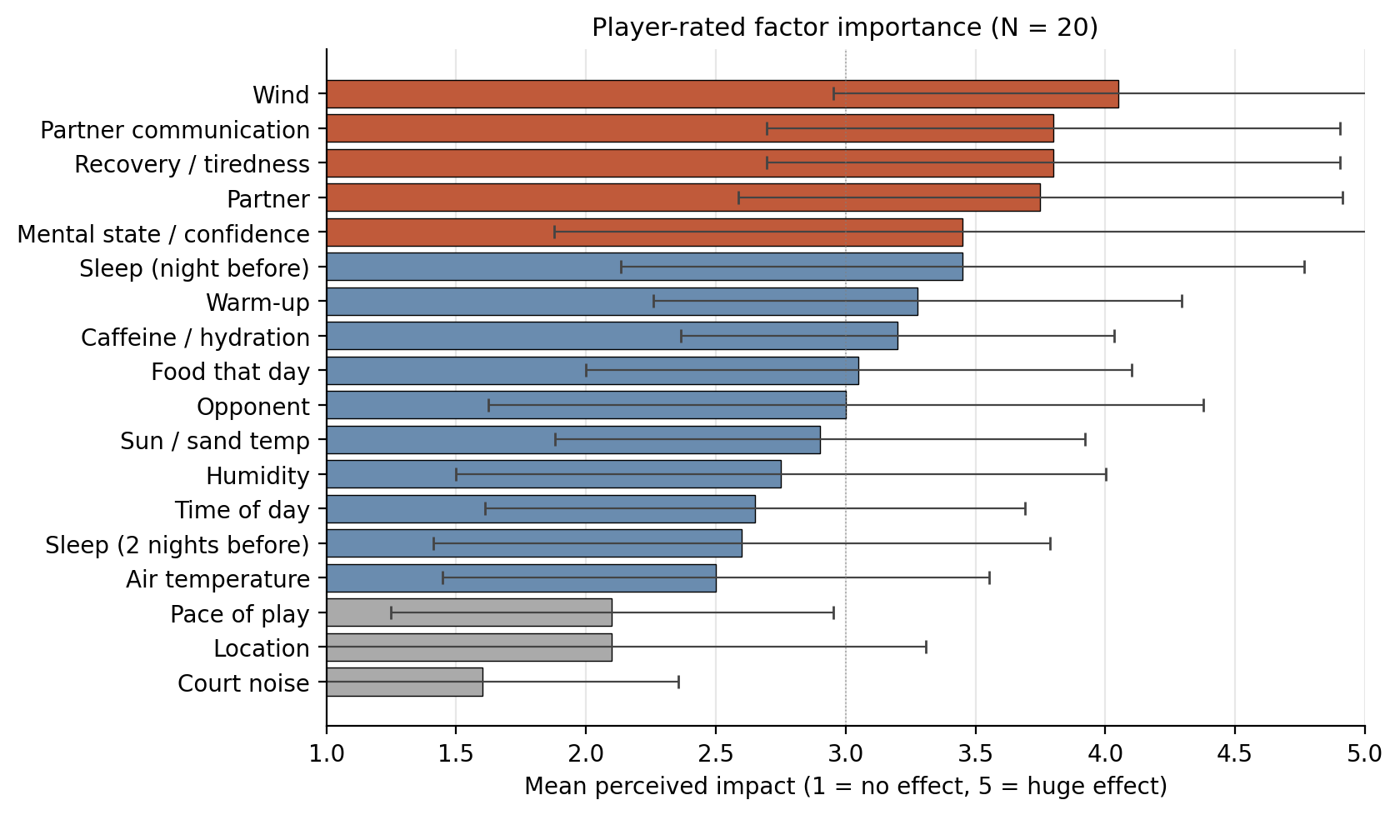
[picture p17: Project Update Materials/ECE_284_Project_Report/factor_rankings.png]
    
    \caption{Player-rated factor importance ($N=20$), mean $\pm$ 1 SD. Wind ranks first overall. Top five (orange) retained as primary engineered features; bottom three (gray) dropped.}
    \label{fig:survey}
\end{figure}

\subsection{Sensor Validation (Bench)}
Each channel was validated for responsiveness (Fig.~\ref{fig:bench}): exhaling on the node produces the expected coupled DHT11 temperature/humidity spike with exponential return to ambient; blowing across the microphone produces clear transient amplitude spikes above a stable baseline; and the MLX90614 tracks a warm surface in its field of view (an immediate $\sim$10\,$^\circ$C rise aimed at skin). The Oura API pipeline was separately validated against a 21-day rolling window (Fig.~\ref{fig:oura}).

\begin{figure}[t]
    \centering
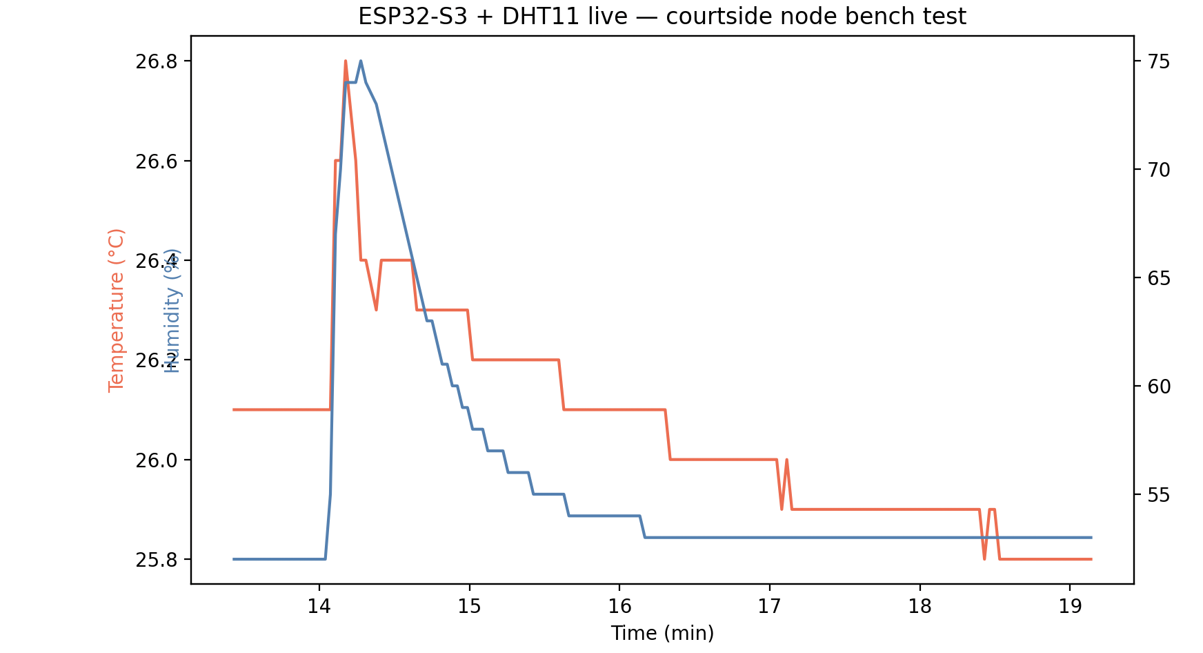
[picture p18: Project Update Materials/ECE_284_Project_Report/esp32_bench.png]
    \hfill
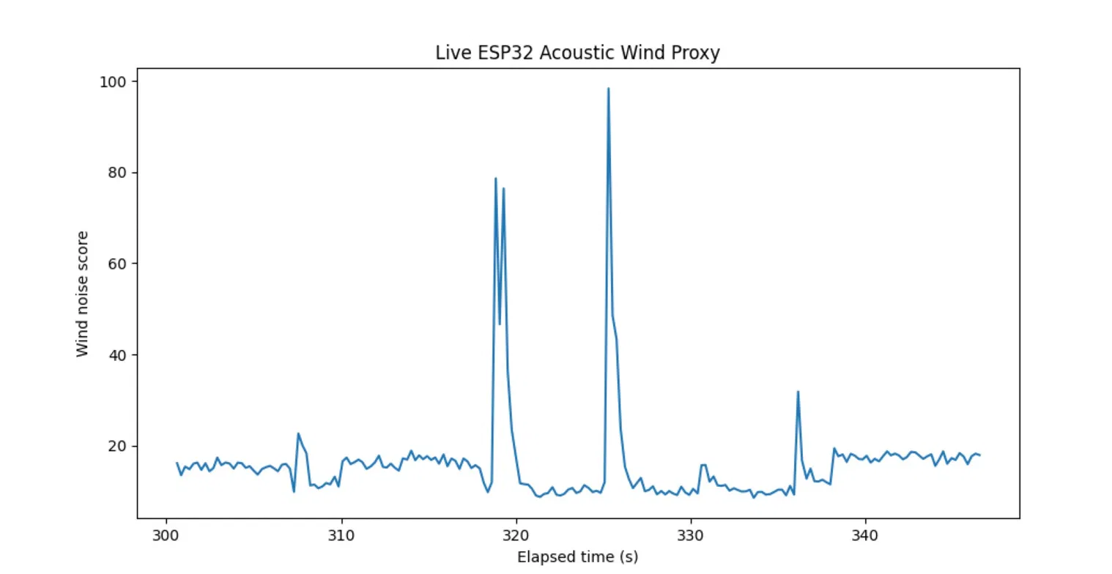
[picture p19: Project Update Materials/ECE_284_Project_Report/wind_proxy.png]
    
    \caption{Bench validation. Left: an exhalation event produces a coupled temperature/humidity response. Right: the acoustic wind proxy responds to blown-air transients above a stable baseline.}
    \label{fig:bench}
\end{figure}

\begin{figure}[t]
    \centering
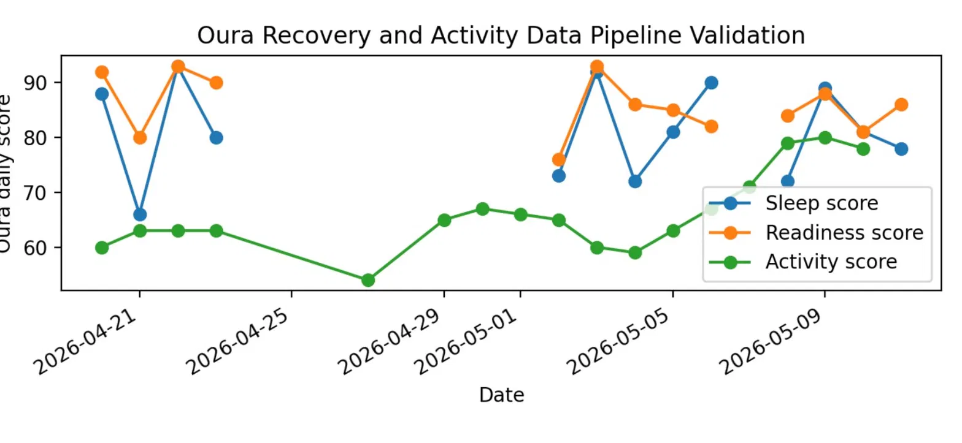
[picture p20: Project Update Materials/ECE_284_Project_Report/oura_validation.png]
    
    \caption{Oura recovery pipeline validated over a rolling multi-week window (HRV, resting HR, sleep), providing an independent cross-check on the Apple Watch recovery stream.}
    \label{fig:oura}
\end{figure}

\subsection{Live Courtside Pilot}
The full wireless path was exercised on the beach (Fig.~\ref{fig:teaser}, Fig.~\ref{fig:applive}): the node ran from a USB battery, joined the phone hotspot, and streamed to the cloud while the athlete used the live dashboard to position the tripod. On instrumented beach days we recorded real sessions with sand-surface temperatures of \textbf{40.3--40.7\,$^\circ$C} against $\sim$26\,$^\circ$C air---directly demonstrating the court-level microclimate that weather data cannot capture---tagged with real partners (e.g., a session at South Mission Beach) and real ratings. Apple Watch recovery for the same windows arrived automatically (HRV, resting HR, sleep), and Volleyball workouts were ingested with in-session heart rate (average 140--172\,bpm, peak up to $\sim$186\,bpm) and active energy (160--459\,kcal); Figure~\ref{fig:recovery} shows this real wearable data populated live in the app. The build step assembled a $\sim$40-column multi-modal feature row per session, confirming end-to-end fusion. In total, the pilot produced \textbf{two fully-instrumented sessions} carrying every stream simultaneously---enough to prove the fusion end-to-end, but not enough for inferential ranking.

\begin{figure}[t]
    \centering
    
    \caption{The Summary recovery panel with \textbf{real} pilot wearable data: HRV (SDNN), resting HR, sleep, the in-session heart rate from a timestamp-paired Volleyball workout (avg 172, max 186\,bpm), and active energy---flowing automatically from the Apple Watch into the deployed app.}
    \label{fig:recovery}
\end{figure}

\subsection{Pipeline Demonstration (Sample Data)}
Because the number of \emph{fully-instrumented} real sessions is currently too small for interpretable ranking---\textbf{only $N{=}2$ sessions to date carry every stream simultaneously}, and a correlation over a handful of points can exceed 0.8 by chance---we ran the unmodified pipeline on a clearly-labeled sample dataset of 16 sessions \emph{built around those two real sessions}: it matches their observed value ranges (e.g.\ $\sim$40\,$^\circ$C sand and the measured heart-rate and sleep ranges) and adds a planted plausible structure (better sleep/HRV and cooler, calmer conditions $\rightarrow$ higher rating). The pipeline recovers that structure (Fig.~\ref{fig:sim}): HRV correlates positively ($r\approx0.67$) and sand-surface temperature negatively ($r\approx-0.36$) with the rating, and the leave-one-session-out stability column flags which factors are robust. This demonstrates \emph{what the instrument produces at scale}, not a finding.

\begin{figure}[t]
    \centering
    
    \caption{Pipeline factor-ranking \emph{output} on a labeled \textbf{sample} 16-session dataset built around the pilot's $N{=}2$ real sessions (not real results). Demonstrates the end-to-end analysis and its self-reported stability; real-data ranking awaits sufficient $N$.}
    \label{fig:sim}
\end{figure}

The instrument also produces targeted, personally-actionable relationship views (Fig.~\ref{fig:demorel}). Pairing each Apple Watch workout to its node session window by \emph{timestamp overlap} yields \emph{actual effort} (in-session heart rate) alongside \emph{reported performance}; overnight \emph{sleep} can likewise be plotted against performance. On sample data, sleep tracks self-rated performance more strongly than raw physical effort---exactly the contrast the tool is designed to surface, and a reminder that more effort is not more performance.

\begin{figure}[t]
    \centering
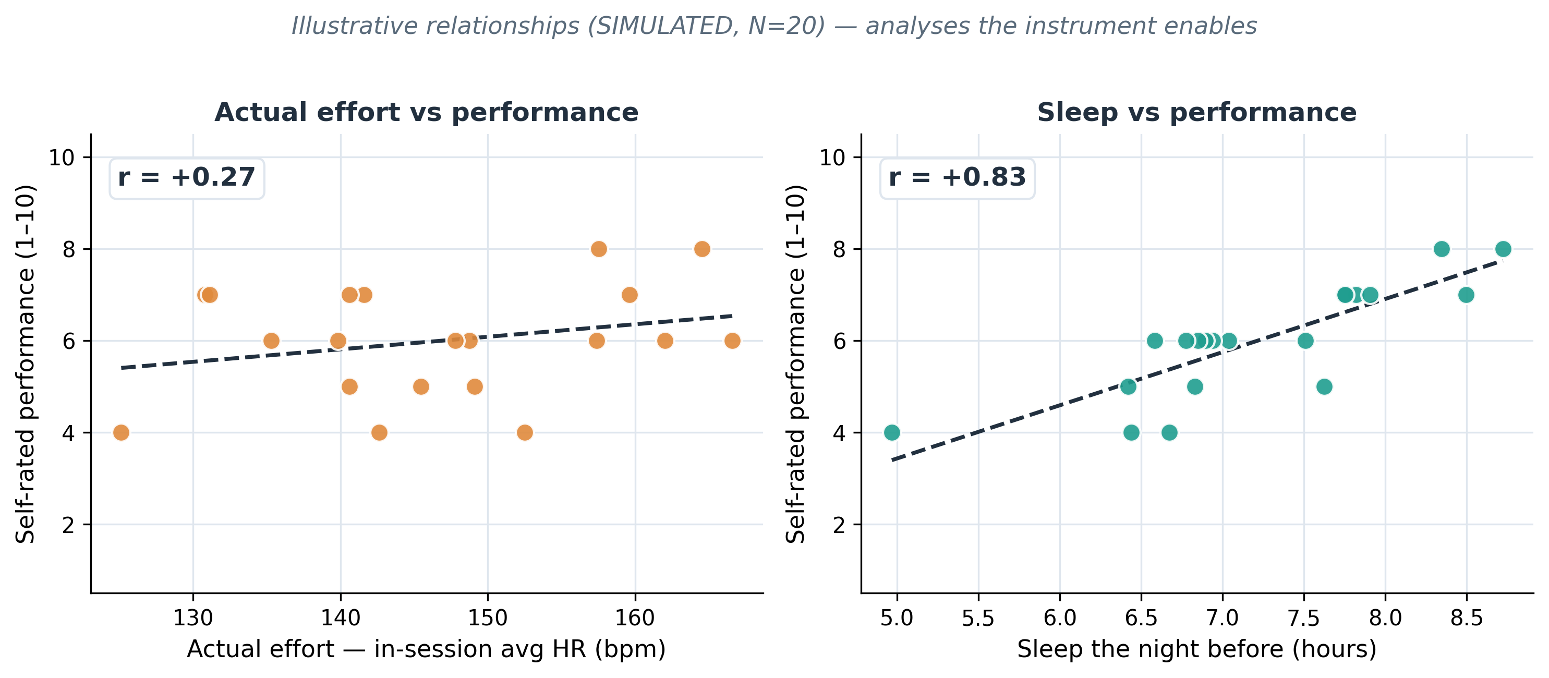
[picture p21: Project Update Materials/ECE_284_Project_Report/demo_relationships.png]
    
    \caption{Relationship views the instrument produces from paired streams (\textbf{sample data} built around the pilot's $N{=}2$ real sessions): actual effort (watch in-session HR, timestamp-matched to the node session) vs.\ self-rated performance (left), and sleep vs.\ performance (right). Shown to illustrate the analysis; not a real-data finding.}
    \label{fig:demorel}
\end{figure}

%===================================================================
\section{Discussion}
\label{sec:discussion}
%===================================================================
\textbf{What worked.} The hardest integration risks---untethered wireless streaming from a beach, automated wearable ingestion, and time-aligned multi-modal fusion across six streams---are all working and deployed. The court-level microclimate signal ($\sim$40\,$^\circ$C sand vs.\ $\sim$26\,$^\circ$C air) is real and is precisely the value a single wearable or weather app misses.

\textbf{Where the value lies.} Given the sample size, we are explicit that the contribution is \emph{not} statistical. The value of this project is (i) the technology---a genuinely working, deployed, multi-modal instrument; (ii) the user-needs study that grounds it; (iii) filling a real gap no existing tool addresses; and (iv) an extensible platform with clear potential. We make no inferential claims on the real data.

\textbf{Honest limitations.} \emph{Small $N$ is the dominant limitation}: factor ranking on the two fully-instrumented sessions to date is not interpretable, so all real output is framed descriptively and the pipeline reports its own instability. \emph{Wind sensing is fundamentally hard with this hardware}: estimating true wind speed from a single small microphone behind a port is essentially not possible---a credible anemometric estimate would need a higher-quality sensor and likely several of them. The current proxy is therefore qualitative, validated against self-reported wind and regional weather rather than against a calibrated anemometer, and more field validation is needed. \emph{Sensor placement is fixed} within the enclosure: the whole node can be rotated to face the wind correctly, but doing so also re-aims the IR sensor, a coupling a future revision should decouple. \emph{Sensor fidelity:} the DHT11 is low-resolution ($\pm$2\,$^\circ$C, $\pm$5\%\,RH, no pressure). \emph{Ground truth:} the subjective 1--10 rating is the primary outcome; kills/errors are secondary and heavily confounded by partner and opponent in 2v2 play, which is exactly why we added peer/coach ratings and the relational analytics rather than over-trusting raw counts.

\textbf{Scope cuts (and the roadmap).} Two stretch goals were deliberately cut to keep the core robust, and both are planned as I continue this as a personal project. \emph{Computer-vision performance metrics}---automated kills, digs, reach, vertical jump, and score tracking---are feasible with existing technology and mainly need integration. \emph{Voice EMA / partner-communication capture} would lower in-session reporting burden. Neither was essential to proving the instrument.

\textbf{Reviewer feedback addressed.} Per TA and classmate feedback: the report is structured with clearly-marked sections and judicious, high-resolution figures; the survey is elevated as user-need validation; the kills/errors confound is reframed with peer/coach ground truth and relational context; an evaluation section reports what is measurable at current $N$ plus a concrete plan; and the analysis is a committed, specified four-stage pipeline.

\textbf{Generalization.} The patterns---time-aligning heterogeneous low-cost streams, capturing microclimate that regional data misses, small-$N$ feature ranking with honest stability reporting, and spatial/relational context---transfer to other outdoor, individually-variable, heat-exposed settings (e.g., heat-exposed workers).

%===================================================================
\section{Conclusion}
%===================================================================
We delivered a working, deployed multi-modal instrument and analysis pipeline that fuses court-level environmental sensing, wearable recovery and in-session intensity, regional weather, spatial (court) and relational (partner/opponent) context, and subjective performance for an individual beach volleyball athlete---grounded in a 20-player needs survey and validated end-to-end on a live beach pilot. The main takeaway: the integration is real and the court microclimate it captures is genuinely invisible to existing tools; the honest gap is sample size, and because the instrument now collects all streams at near-zero marginal effort, the remaining work---reaching enough sessions and re-running the already-built ranking---is straightforward. We present sample-data output (built around the pilot's $N{=}2$ real sessions) to show what the system produces at scale, and we make no statistical claims on the small real sample.

\section*{AI Use Disclosure}
AI tools (Claude) were used as a pair-programming and drafting assistant for the firmware, backend, and web-app code, for editing this report's prose, and to summarize open-ended survey responses. All system design, hardware integration, data-collection methodology, analysis choices, and the underlying data are the author's own. No AI tools were used during oral assessments.

\begin{thebibliography}{9}
\bibitem{casa2015} D.~J. Casa et al. National Athletic Trainers' Association position statement: exertional heat illnesses. \emph{Journal of Athletic Training}, 2015.
\bibitem{shiffman2008} S.~Shiffman, A.~A. Stone, and M.~R. Hufford. Ecological momentary assessment. \emph{Annual Review of Clinical Psychology}, 4:1--32, 2008.
\bibitem{lundberg2017} S.~M. Lundberg and S.-I. Lee. A unified approach to interpreting model predictions. \emph{Advances in Neural Information Processing Systems (NeurIPS)}, 2017.
\bibitem{sklearn} F.~Pedregosa et al. Scikit-learn: machine learning in Python. \emph{Journal of Machine Learning Research}, 12:2825--2830, 2011.
\bibitem{openmeteo} Open-Meteo. Free open-source weather API. \url{https://open-meteo.com}, accessed 2026.
\bibitem{marzano2024} A.~Marzano-Felisatti et al. Electronic performance-tracking of physical-conditional performance in young male beach volleyball players. 2024.
\bibitem{sussex} University of Sussex. Wearables in Beach Volleyball project. Accessed 2026.
\end{thebibliography}

\end{document}

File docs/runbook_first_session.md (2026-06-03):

# First Data Collection — Runbook

Goal: capture one synchronized session (court sensors + Apple Watch + a logged
self-rating). Two connection options below — **use Option A for the first session**
(most reliable), move to Option B (Render) once it's proven.

---

## Pre-flight (do at home, before the beach)

**Hardware**
- [ ] MLX90614 header **soldered** (loose pins = no IR). Optional for first run —
      IR just logs `null` if absent; everything else still works.
- [ ] Sensors seated: DHT11 → GPIO2, mic OUT → GPIO4, MLX SDA→21 / SCL→20.
- [ ] Power bank charged.

**Firmware** (`firmware/include/secrets.h`)
- [ ] `USE_WIFI 1`
- [ ] `WIFI_SSID` / `WIFI_PASSWORD` = your **iPhone hotspot** name + password
- [ ] `BACKEND_URL` = `http://172.20.10.2:8000`  (typical laptop IP on an iPhone
      hotspot — confirm at the beach, see Option A step 2)
- [ ] Flash: `cd firmware && python3 -m platformio run -t upload` (in `.venv_pio`)
- [ ] Serial monitor sanity check (`platformio device monitor -b 115200`):
  - `#   found 0x5A` (if MLX soldered)
  - DHT temp/humidity look real, mic not stuck at 4095
  - `# WiFi: connected (IP ...) -> POSTing to ...`

**Backend** — confirm it runs (one command):
```bash
bash scripts/run_backend.sh        # prints the URL + your current IP
```
Open `http://localhost:8000` → dashboard loads. Ctrl-C to stop until the beach.
(To start the session with a clean DB: `rm ~/courtside_data.db` first.)

---

## Option A — laptop on the hotspot (use this first) ✅

No internet needed; laptop sits in a shaded bag.

1. **iPhone:** Settings → Personal Hotspot **ON**; turn **Maximize Compatibility ON**
   (forces 2.4 GHz — the ESP32-S3 is 2.4 GHz only).
2. **Laptop:** join the hotspot WiFi, then `bash scripts/run_backend.sh`. Note the
   printed hotspot IP (usually `172.20.10.2`). If it differs from `BACKEND_URL` in
   `secrets.h`, update it and reflash.
3. **Node:** plug into the power bank. It boots → joins the hotspot → starts POSTing.
4. **Phone:** open `http://<laptop-ip>:8000`. Status should turn green **online**.
5. **Position the tripod** using the live sand ring + wind trace.
6. **Apple Watch:** start a workout (Volleyball / Other) so in-session HR is recorded.
7. **Play.**
8. **Log it:** Log-session tab → rating, wind, kills/errors, partner, location
   (type it — geolocation needs https, which Option A lacks), Save.
9. **Stop** the Apple Watch workout.

## Option B — Render cloud (v2, no laptop) ☁️
Deploy once via `render.yaml` (see that file). Then set `BACKEND_URL` to the
`https://…onrender.com` URL and reflash. Beach flow is the same, minus the laptop:
node → iPhone hotspot → Render; phone opens the Render URL (geolocation works).
Open the dashboard first to wake the free service (~30–60 s cold start).

---

## Recovery data (Apple Watch → backend)
Health Auto Export → Automations → **REST API**:
- URL = `<BACKEND_URL>/ingest/health`  (Render URL, or the laptop IP on the hotspot)
- Data Type: Health Metrics · Format: JSON · Aggregate: Days · Batch: ON
- Metrics: HRV, Resting Heart Rate, Sleep Analysis, Respiratory Rate, Heart Rate
- Make a 2nd automation: Data Type **Workouts** (gets the in-session HR trace)
- Hit **Manual Export → today** after the session to push it now.

## After the session
- Data is in `~/courtside_data.db`. Confirm: session in the Log tab, court rows via
  the live view, and the health day arrived (HAE Activity Log shows a 200).
- That's one complete multi-modal session. Repeat to build N.

---

## Troubleshooting
| Symptom | Fix |
|---|---|
| Dashboard never goes "online" | node serial must say "WiFi connected"; `BACKEND_URL` IP must match the laptop's hotspot IP; both on the same hotspot |
| IR / sand stays blank (`null`) | MLX not soldered/detected — check serial for `0x5A` |
| `sound_pp` stuck at 4095 | mic OUT wire floating/shorted — reseat it |
| DHT/mic values flicker or drop | reseat Dupont jumpers; add tape/strain relief |
| node connects but no data on dash | backend must be started with `--host 0.0.0.0` (run_backend.sh does this) |
| node can't reach laptop at all | if macOS prompts "allow incoming connections to Python" → **Allow** (System Settings → Network → Firewall); otherwise it blocks the node |

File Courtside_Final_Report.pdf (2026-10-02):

# Courtside: A Deployed Multi-Modal Sensing Instrument for Contextualizing Beach Volleyball Performance

### Tristan Cooper

UC San Diego
La Jolla, CA, USA
tmcooper@ucsd.edu

### Abstract

Beach volleyball athletes experience large day-to-day performance variability that no single tool explains: wearables report overnight recovery without same-day context, weather services miss court-level microclimate (wind in particular), and mid-match self-report is impractical. We designed, built, and deployed Courtside, a multi-modal sensing instrument that fuses six streams—a custom courtside environmental node (ESP32-S3 with a DHT11 air temperature/humidity sensor, an MLX90614 infrared sand-surface thermometer, and an electret-microphone wind/audio proxy), wearable recovery physiology (Apple Watch via automated HealthKit export and Oura Ring via API), wearable workout intensity (in-session and prior-load), coarse regional weather (Open-Meteo), per-session subjective/objective performance logging, and the spatial and relational context of each session (which court, and which partners and opponents). The node streams over the athlete’s phone hotspot to a cloud backend (FastAPI + PostgreSQL on Render) and a mobile web app that runs live setup, session recording, evaluation entry, an interactive court map, and partner/opponent “personas” with statistically-guarded relationship signals. A four-stage factor-ranking analysis (correlation → sparse linear selection → tree ensembles → SHAP) closes the loop. We validate the instrument end-to-end on a single-athlete pilot—including a 20-respondent player survey that shaped the feature set and a live beach day capturing sand-surface temperatures near 40 ◦C against ∼26 ◦C air, alongside synchronized Apple Watch recovery and in-session heart rate. We frame the contribution honestly: the value is the working instrument, the user-needs study, and the gap it fills—not statistical claims, which the small real sample (N=2 fully-instrumented sessions) cannot support. Where analytics need scale, we demonstrate them on clearly-labeled sample data built around those two real sessions to show the output the instrument produces.

### 1 Motivation

I began this project from my own experience. After starting to play beach volleyball at an elite collegiate level, I found it genuinely hard to tell whether I was improving, to discriminate the quality of one training session from another, and to know what actually drove a good or bad day. Playing with partners of all ages and skill levels, and across very different courts, made clear this is a common problem, not just mine: athletes know some days they play well and others they do not, but isolating why is hard because recovery, environment, game context, and mindset all interact, while existing tools each measure one dimension in isolation—or none at all. Three blind spots. (1) Wearables (WHOOP, Oura, Garmin, Apple Watch) report readiness from overnight HRV and sleep but ignore same-day environmental load and subjective state. (2) Weather

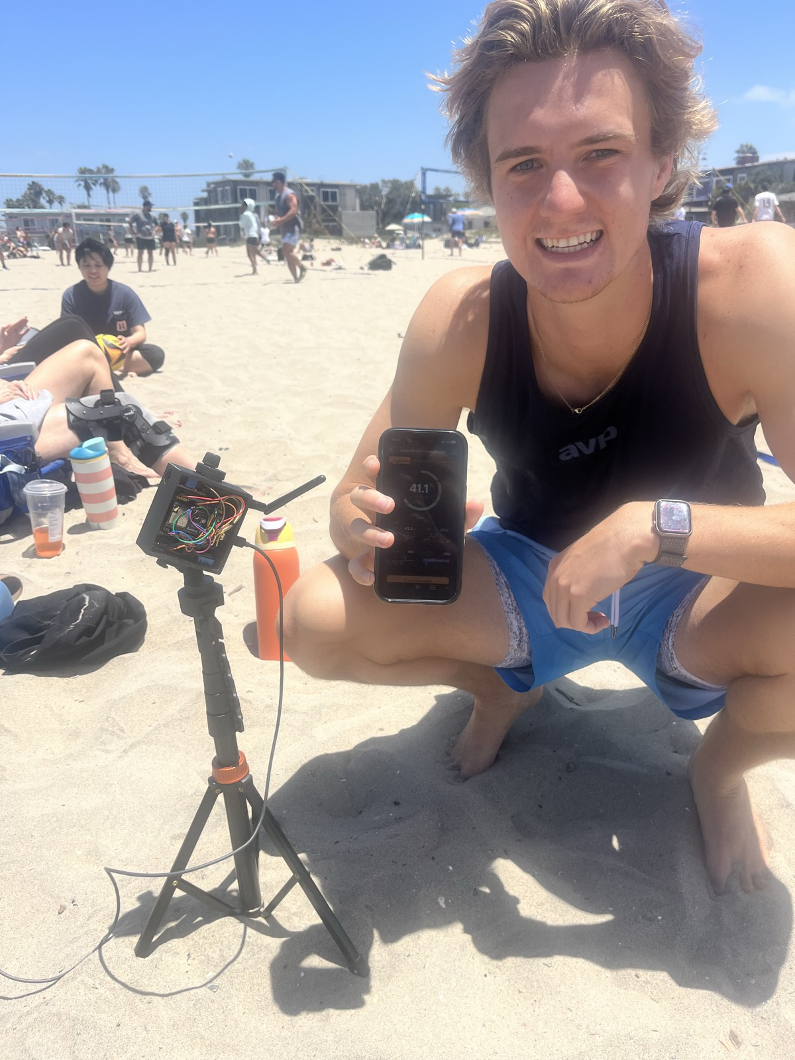
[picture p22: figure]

Figure 1: The whole system in the field. The courtside node runs untethered on a tripod (battery-powered, streaming over the phone’s hotspot); the athlete reads live conditions in the web app while an Apple Watch supplies recovery and in-session heart rate. Everything in this photo is a working part of the deployed instrument.

apps report city-grid conditions and miss court-level microclimate: wind is reshaped by surrounding terrain—the Muir courts on the UCSD campus are ringed by buildings that create a swirling environment which reshapes serve-receive in a way no nearby weather station could capture—and sand-surface temperature varies with grain size, moisture, and direct sun in ways ambient air temperature cannot. (3) Self-evaluation is limited to what an athlete can remember and to their own pattern recognition; it carries heavy confounds (partner, opponent) and places the entire measurement burden on the athlete mid-competition, when compliance collapses. The gap. No system fuses recovery + environment + subjective state + performance—together with where and with whom a session happened—for an individual beach volleyball athlete. Each stream exists in isolation.

1

Tristan Cooper

Who benefits. The immediate end user is the recreational or collegiate beach athlete who today has no way to contextualize why a session felt the way it did. The broader health relevance is exertional-heat safety: beach volleyball is outdoors with no climate control, and early warning for heat strain requires exactly the physiological–environmental–subjective fusion this instrument produces. A sand-surface temperature near 40 ◦C—measured in our pilot—is well above the ∼26 ◦C air temperature a weather app would report for the same moment.

### 2 Related Work

Commercial wearable recovery. WHOOP, Oura, and Garmin produce daily readiness scores from overnight biometrics; validation studies show reasonable resting HRV and sleep accuracy, but these scores are not contextualized against same-day environment or subjective state. Apple Watch exposes HRV (SDNN) and in-workout heart rate via HealthKit. Courtside treats these as one input among several rather than the whole picture.
Environmental monitoring in sport. The FIVB enforces WBGTbased heat protocols at professional events and the NATA publishes heat-illness position statements [1], but these rely on coarse point measurements and are largely absent from recreational and collegiate settings. We bring a low-cost court-level environmental node to exactly that gap.
Ecological momentary assessment (EMA). EMA is well-validated in sport and behavioral health [2]; voice-based capture with modern ASR has been proposed to lower burden. We scope voice EMA out (Section 8) in favor of a low-burden structured post-session form. Wearables in beach volleyball. Prior work targets different questions: Marzano-Felisatti et al. (2024) [6] applied an electronic performance-tracking system to quantify physical-conditional performance of young male players, and the University of Sussex “Wearables in Beach Volleyball” project [7] investigates IMU-based match load and event detection. Both focus on movement classification and training-load quantification from a single modality. Neither fuses physiological recovery, environmental context, spatial/relational context, and subjective experience into a joint per-session analysis.
Gap. No published system performs this multi-modal, individualathlete fusion for beach volleyball.

### 3 Project Aim

Primary aim. Build a working instrument that captures synchronized multi-modal sessions for a single beach volleyball athlete and runs a per-session factor-ranking analysis identifying which contextual streams plausibly explain performance variation. End user: the athlete; output is personally actionable, not a clinical or coaching product. Non-goals: not a deployable predictive model, not cross-sport, not clinically validated.
Following up on the proposal and update. Table 1 maps what was proposed and updated against what was delivered, with honest substitutions. The proposal committed to Oura + Apple Watch + a BME280 environmental node + a subjective rating + 6–10 sessions, with voice EMA and computer-vision (CV) kill/error extraction as stretch goals. The update reported the survey, bench-validated

Table 1: Proposed/updated vs. delivered. ✓ delivered, ∼ substituted, + added beyond proposal, × de-scoped.

Component | Proposed/Update | Final
Wearable recovery (Oura) | API pull | ✓ API
Wearable (Apple Watch) | HealthKit | ✓ auto HealthKit export
In-session HR / workouts | stretch | ✓ parsed (avg/max/energy)
Air temp / humidity | BME280 | ∼ DHT11
Sand-surface temp (IR) | MLX90614 | ✓ MLX90614
Wind proxy (acoustic) | mic | ✓ mic (qualitative)
Regional weather context | — | + Open-Meteo
Web app / live capture | local logging | ✓ cloud app + recording
Court map (spatial) | — | + interactive map
Partner/opponent personas | — | + relational analytics
Subjective outcome | 1–10 rating | ✓ rating (+ peer/coach)
4-stage analysis | planned | ✓ implemented
Voice EMA | stretch | × de-scoped
CV kill/error outcome | stretch | × de-scoped
≥6 full-stream sessions | target | × small N (limitation)

sensing, and an MLX90614 in transit. For the final system, the environmental sensing, wearable ingestion, web app, and analysis pipeline were all delivered and deployed; the BME280 was substituted with a DHT11; the app additionally grew spatial (court map) and relational (partner/opponent personas) dimensions that were not in the proposal; and voice EMA and CV were de-scoped to keep the core instrument robust. The dominant gap versus the proposal is session count: collegiate season timing and hardware lead times compressed real data collection.

### 4 System Architecture and Implementation

The engineering is the heart of this project, so we describe the deployed system in detail. Figure 2 shows the end-to-end data path; it is a live system, not a mockup.

### 4.1 Courtside Environmental Node

An ESP32-S3 microcontroller (Fig. 3) reads three channels at 1 Hz: a DHT11 (air temperature and humidity, one-wire digital); an MLX90614 non-contact infrared thermometer (sand-surface temperature, I²C address 0x5A) that senses emitted infrared and therefore requires no contact and no exposed window (plastic blocks infrared, so the enclosure leaves an open aperture aimed at the sand); and an analog electret microphone whose 50 ms peak-topeak amplitude serves as a low-cost wind/audio proxy. A deliberate hardware detail: the microphone is read on an ADC1 pin, because the ESP32’s ADC2 is commandeered by the WiFi radio—reading the mic on ADC2 would silently fail whenever the radio is active. The electronics are housed in a custom 3D-printed enclosure designed in Fusion 360 (Fig. 4) with a louvered vent for the air sensor, an open IR aperture, a foam-screened microphone port, and a 1/4-20 thread so the node mounts on a standard camera tripod and can be raised, leveled, and rotated on site. The node runs untethered from a USB power bank. Figure 3 shows the internals: the printed lid (left) carries custom standoffs and cutouts that seat each sensor at its aperture, while the body (right) holds the board, the tripod boss, and the sensor harness.

2

Courtside: A Deployed Multi-Modal Sensing Instrument for Contextualizing Beach Volleyball Performance

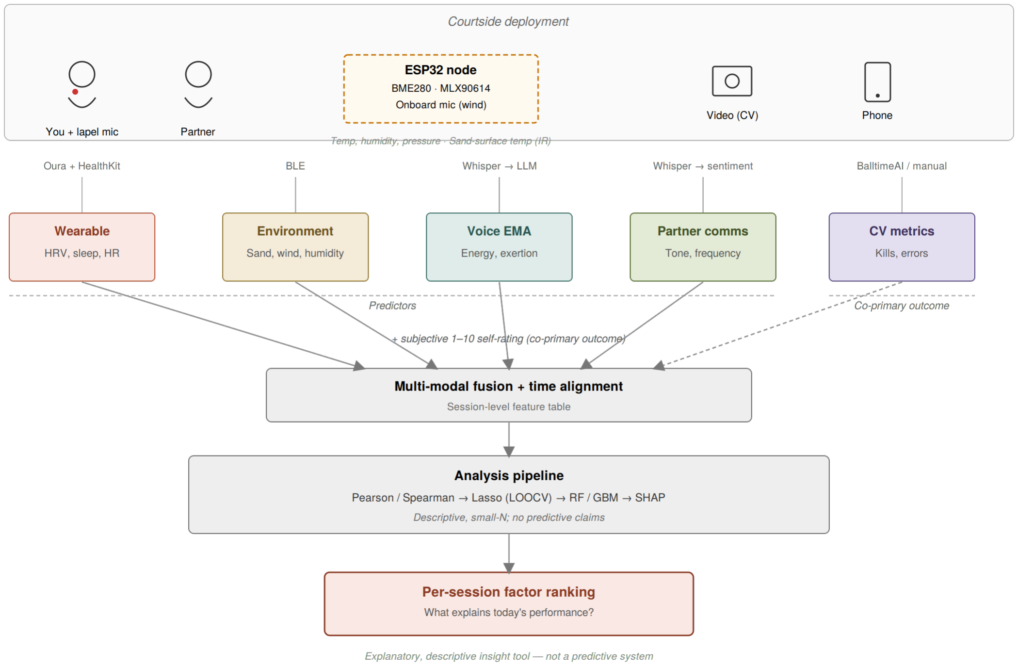
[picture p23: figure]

Figure 2: System architecture. The courtside node streams sensor readings over the athlete’s phone hotspot to a cloud backend; the Apple Watch and Oura push recovery and workout data to the same backend; the athlete logs subjective/objective outcomes from the mobile web app. All streams are time-aligned into one per-session feature table feeding the four-stage factor-ranking analysis.

### 4.2 Firmware and Connectivity

The firmware (C++/Arduino, built in PlatformIO) connects to the athlete’s iPhone Personal Hotspot as a WiFi station and HTTP-POSTs each reading as JSON to the backend, authenticated by a node key. It includes a boot-time I²C bus scan that prints discovered addresses for field debugging, and a serial-CSV fallback so the node still logs if connectivity drops. Because the ESP32-S3 is 2.4 GHz only, the hotspot is set to maximize-compatibility mode. This wirelessover-hotspot path is what lets the system run on a beach with no laptop and no SD card.

### 4.3 Cloud Backend and Data Model

A FastAPI service backed by PostgreSQL is deployed on Render and auto-deploys on each push. It exposes ingest endpoints (court readings, health, workouts), a session CRUD and recording API, people/personas, an aggregated court endpoint for the map, a relationship-signals endpoint, and a full export for the offline pipeline. The schema separates concerns into court_readings, health_daily (one row per day×source), sessions, workouts, and—added for the relational features—people and a session_people link table. Every wearable payload is retained losslessly in a raw JSON column so new signals can be promoted later without re-collection, and a lightweight auto-migration adds new model columns to the live database on deploy.

### 4.4 Mobile Web App

The app (vanilla JS, no build step, installable as a phone web app) is the instrument’s user surface. Figure 5 shows it running live over cellular on the first instrumented beach day. It provides a live setup view with real-time per-sensor plots and a heuristic check (it warns when the IR reading ≈ air temperature, indicating the sensor is not yet aimed at the sand); a recording flow that bookmarks each session’s start/stop so its sensor time-series window is captured; and an evaluation form capturing the subjective 1–10 self-rating, optional peer/coach ratings, felt-wind, kills/errors, player state (energy, soreness, mental, warm-up, food timing), partner/opponents, location, notes, and geolocation.

### 4.5 Wearable and Weather Ingestion

Apple Watch data syncs automatically via the Health Auto Export app’s REST automation, posting HRV (SDNN), resting heart rate, sleep, respiratory rate, and workouts to the backend, upserted by date. Oura is pulled via its v2 API as a second recovery source, enabling cross-validation (Apple SDNN vs. Oura RMSSD). Open-Meteo [5] supplies coarse regional weather (wind, gust, temperature,

3

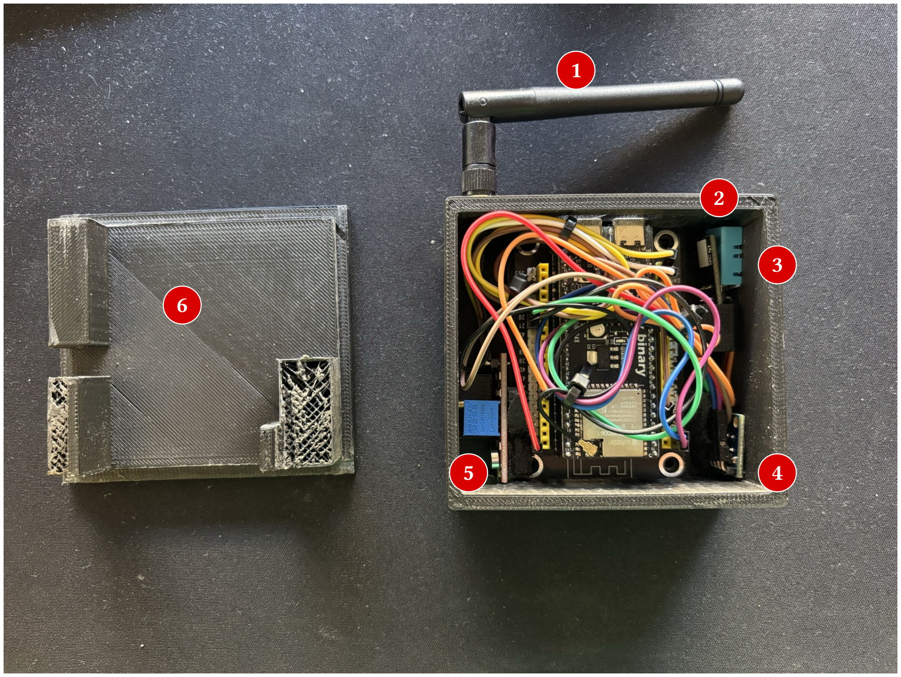
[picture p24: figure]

Figure 3: Inside the node. 1 ESP32-S3 antenna; 2 USB-C power;

### 3 DHT11 air temperature/humidity (top-right); 4 MLX90614

infrared sand-surface sensor (bottom-right); 5 electret microphone wind/audio proxy (bottom-left); 6 3D-printed lid with custom cutouts and standoffs that seat each sensor. (Callout positions per the build layout.)

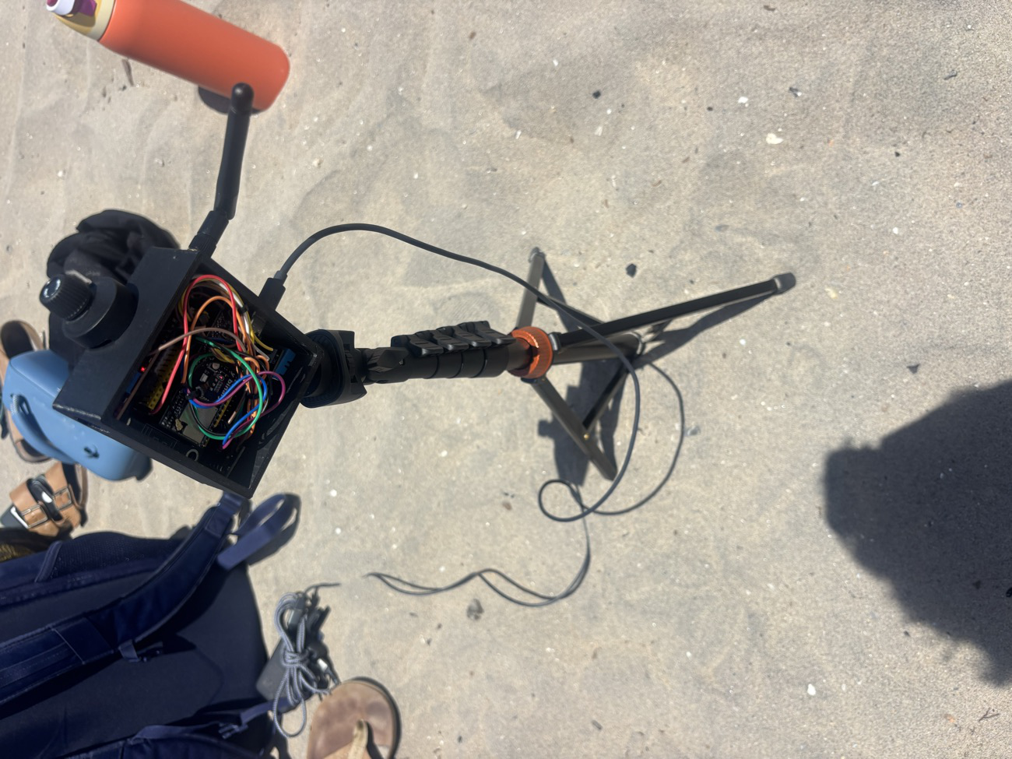
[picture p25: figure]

Figure 4: Left: the node deployed courtside on sand, tripodmounted and battery-powered. Right: the enclosure CAD (Fusion 360)—louvered air-sensor vent, open IR aperture, and tripod mount.

humidity), kept clearly separate from on-court sensor readings— context, not mixed-in measurement.

### 4.6 Spatial Context: the Court Map

Because the app already captures geolocation, sessions are grouped by court and plotted on an interactive map (Fig. 6). Each marker is colored by the athlete’s average rating there; tapping a court reveals its session count, average rating, average node-measured wind and surface temperature, and who the athlete has played with at that court. This makes “I play better at La Jolla Shores than at Ocean Beach” a queryable, visual fact rather than a vague impression.

### 4.7 Relational Context: Partner/Opponent Personas

Beach volleyball is a 2v2 game and, candidly, a deeply relational and emotional one—who you play with and against shapes both performance and experience. Courtside therefore promotes partners and opponents from free text to first-class people records that accrue history. For each person the app shows the athlete’s average rating with them (as partner) or against them (as opponent), a self-rated skill, and an estimated skill derived from results—a partner who consistently lifts the athlete’s rating, or an opponent who consistently lowers it, reads as stronger (Fig. 7, right).
Crucially, the app surfaces relationship signals as notifications (Fig. 7, left). For each person with enough sessions, it compares the athlete’s ratings with versus without that person using a Welch’s t-test (implemented in pure Python so the web service stays dependencylight), and flags notable, small-N-guarded effects: “you play your best with Maya,” or “tough matchup against Daniel.” This operationalizes the intuition every athlete has—“of course I played badly, I was up against the best player there”—into an explicit, evidenceweighted prompt. As with the pipeline, these analytics are shown on labeled sample data because the real pairing history is not yet large enough for inference.

### 5 Design Decisions and Development History

The system arrived at its present form through a sequence of deliberate decisions; we recount them as a narrative (ordered, undated) because the reasoning is the contribution.
Survey before silicon. Before investing further in hardware we ran a 20-player needs survey (Section 7) to decide what to sense. Wind ranking first is the reason the acoustic wind proxy survived and court noise and pace-of-play were dropped.
Sensor selection and an honest substitution. The proposal specified a BME280 (temperature, humidity, pressure). When the on-hand part proved unreliable, we substituted a DHT11 to keep air temperature and humidity working, accepting the loss of barometric pressure and lower resolution—a pragmatic trade we flag as a limitation rather than hide. The MLX90614 was chosen specifically because infrared sensing needs no ground contact and no fragile window.
Bench-first bring-up. Each sensor was validated on the bench before field use (Fig. 10, Fig. 8), and the firmware gained an I²C scanner so a missing sensor is diagnosable in seconds on the sand. The pivotal pivot: from scripts to a cloud instrument. The original plan logged to a laptop over USB. We realized this is unusable on a beach, and re-architected around the athlete’s phone: the node streams over the phone hotspot to a cloud backend, and the phone itself is the live dashboard. This single decision—no laptop, no SD card—is what makes the instrument genuinely field-usable. The app as the instrument, not an afterthought. Once the data lived in the cloud, the web app became the product surface: live setup, recording windows, and evaluation entry replaced a clipboard and a spreadsheet.
Frictionless wearable capture. Rather than manual exports, we adopted Health Auto Export’s REST automation so Apple Watch recovery and workouts arrive on their own, and kept Oura as an independent cross-check.
Spatial and relational dimensions last. With the core solid, we added the court map and the partner/opponent persona system— the features that most directly serve the “relationship sport” nature of beach volleyball—each backed by real database tables so they grow with use.

4

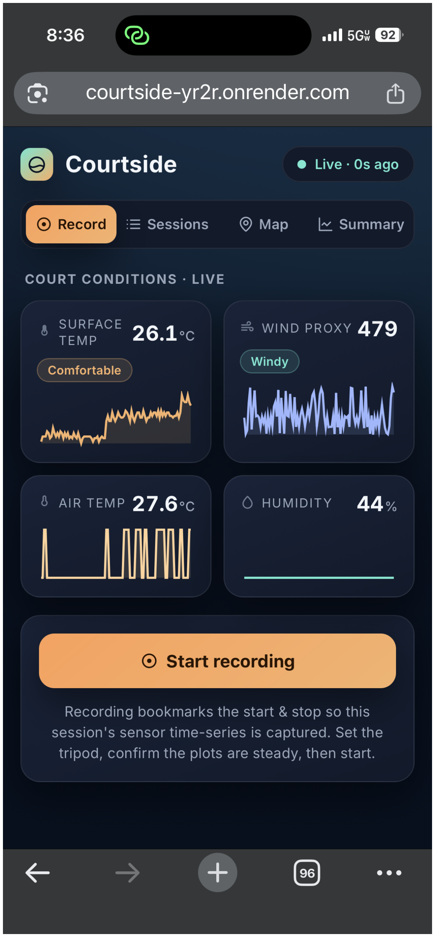
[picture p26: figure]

Figure 5: The deployed app on the athlete’s phone over 5G, with four tabs (Record, Sessions, Map, Summary). Left: the live setup view (“Live · 0s ago”) with balanced per-sensor cards and a “Comfortable/Windy” interpretation. Center: the post-session evaluation form, including the survey-driven player-state sliders (energy, soreness, mental, warm-up). Right: the session list—the June entries are real pilot sessions (sand 40.3–40.7 ◦C against ∼26 ◦C air, workout-paired), interleaved with sample sessions used for demonstration.

### Fabrication

The node was hand-built and hand-soldered (Fig. 8, left), with each subsystem brought up and smoke-tested individually before integration (Fig. 8, right shows the first working IR read).

### 6 Methodology 6.1 Data Handling and Feature Engineering

Sensor rows are stamped with server-receive time. Each logged session windows the node readings to its recording interval and aggregates them (mean/max sand and air temperature, mean humidity, mean and 95th-percentile wind-audio). Daily wearable recovery joins by date (Apple preferred, Oura fallback and cross-check). Apple Watch workouts overlapping the session window yield in-session intensity (average/max HR, active energy); workouts in the prior seven days yield a cross-training load feature. Regional weather is attached per session location, and partner/opponent links attach the relational context. The unit of analysis is the session— appropriate given small N—producing one tidy multi-modal feature row per session (∼40 columns).

### 6.2 Analysis Pipeline

The analysis is exploratory and descriptive, in four small-N-aware stages: (1) Pearson and Spearman correlations of each feature against the subjective rating; (2) Lasso regression with leave-one-out cross-validation for sparse feature selection; (3) random-forest and gradient-boosting feature importances to capture interactions; (4) SHAP values [3] from the gradient-boosting model for per-factor attribution. We additionally compute leave-one-session-out top-3 stability. The pipeline (scikit-learn [4]) degrades gracefully: below a sample threshold it emits correlations plus an explicit caveat rather than fabricating a model. No p-values are reported as confirmatory, and no model is released for deployment.

### 6.3 Relationship Statistics

For the relational signals, each person’s with-set and without-set of ratings are compared with a two-sided Welch’s t-test (unequal variance), with the p-value computed from the regularized incomplete beta function in pure Python. Signals fire only with ≥3 sessions for the person, an effect of ≥0.8 rating points, and p < 0.1—thresholds chosen to be informative on small samples while explicitly labeled preliminary.

5

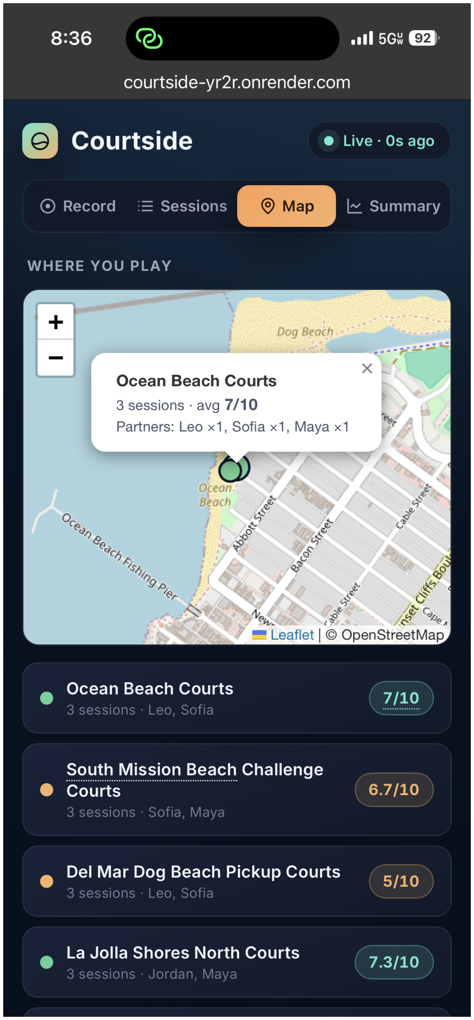
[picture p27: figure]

Figure 6: The Map view with a court tapped open: session count, average rating, and who the athlete has played with there, over markers colored by average rating. Populated mostly with sample data to demonstrate the feature; the pilot’s real courts appear here too.

### 6.4 Evaluation Criteria

Because the output is a per-session explanation rather than a prediction, standard ML metrics do not apply. We evaluate on engineering criteria: data completeness (fraction of sessions with all streams captured), time alignment (streams aligned to server-receive time and the recording window), sensor responsiveness (bench validation per channel), and ranking stability / face validity (leave-onesession-out stability and comparison of top factors to the athlete’s recollection)—the latter two meaningful only once N is sufficient.

### 7 Results 7.1 User-Need Validation (N=20)

Before further hardware investment we surveyed 20 players (UCSD men’s/women’s beach teams plus recreational, club, NCAA, and Open/AVP players) to validate need and prioritize features (Fig. 9). Wind ranked first (4.05/5), validating the decision to prioritize wind sensing; recovery/tiredness, mental state, partner identity, and partner communication completed the top five; court noise, location, and pace of play ranked lowest and were dropped from the feature plan. Open responses repeatedly raised food timing, soreness, and warm-up quality, motivating the lightweight player-state inputs. Across the cohort, 85% expressed positive interest, with qualified interest centered on wearable integration and minimal in-session burden.

### 7.2 Sensor Validation (Bench)

Each channel was validated for responsiveness (Fig. 10): exhaling on the node produces the expected coupled DHT11 temperature/humidity spike with exponential return to ambient; blowing across the microphone produces clear transient amplitude spikes above a stable baseline; and the MLX90614 tracks a warm surface in its field of view (an immediate ∼10 ◦C rise aimed at skin). The Oura API pipeline was separately validated against a 21-day rolling window (Fig. 11).

### 7.3 Live Courtside Pilot

The full wireless path was exercised on the beach (Fig. 1, Fig. 5): the node ran from a USB battery, joined the phone hotspot, and streamed to the cloud while the athlete used the live dashboard to position the tripod. On instrumented beach days we recorded real sessions with sand-surface temperatures of 40.3–40.7 ◦C against ∼26 ◦C air—directly demonstrating the court-level microclimate that weather data cannot capture—tagged with real partners (e.g., a session at South Mission Beach) and real ratings. Apple Watch recovery for the same windows arrived automatically (HRV, resting HR, sleep), and Volleyball workouts were ingested with in-session heart rate (average 140–172 bpm, peak up to ∼186 bpm) and active energy (160–459 kcal); Figure 12 shows this real wearable data populated live in the app. The build step assembled a ∼40-column multi-modal feature row per session, confirming end-to-end fusion. In total, the pilot produced two fully-instrumented sessions carrying every stream simultaneously—enough to prove the fusion end-to-end, but not enough for inferential ranking.

### 7.4 Pipeline Demonstration (Sample Data)

Because the number of fully-instrumented real sessions is currently too small for interpretable ranking—only N=2 sessions to date carry every stream simultaneously, and a correlation over a handful of points can exceed 0.8 by chance—we ran the unmodified pipeline on a clearly-labeled sample dataset of 16 sessions built around those two real sessions: it matches their observed value ranges (e.g. ∼40 ◦C sand and the measured heart-rate and sleep ranges) and adds a planted plausible structure (better sleep/HRV and cooler, calmer conditions → higher rating). The pipeline recovers that structure (Fig. 13): HRV correlates positively (r ≈ 0.67) and sand-surface temperature negatively (r ≈ −0.36) with the rating, and the leave-one-session-out stability column flags which factors are robust. This demonstrates what the instrument produces at scale, not a finding.
The instrument also produces targeted, personally-actionable relationship views (Fig. 14). Pairing each Apple Watch workout to its node session window by timestamp overlap yields actual effort (in-session heart rate) alongside reported performance; overnight sleep can likewise be plotted against performance. On sample data, sleep tracks self-rated performance more strongly than raw physical

6

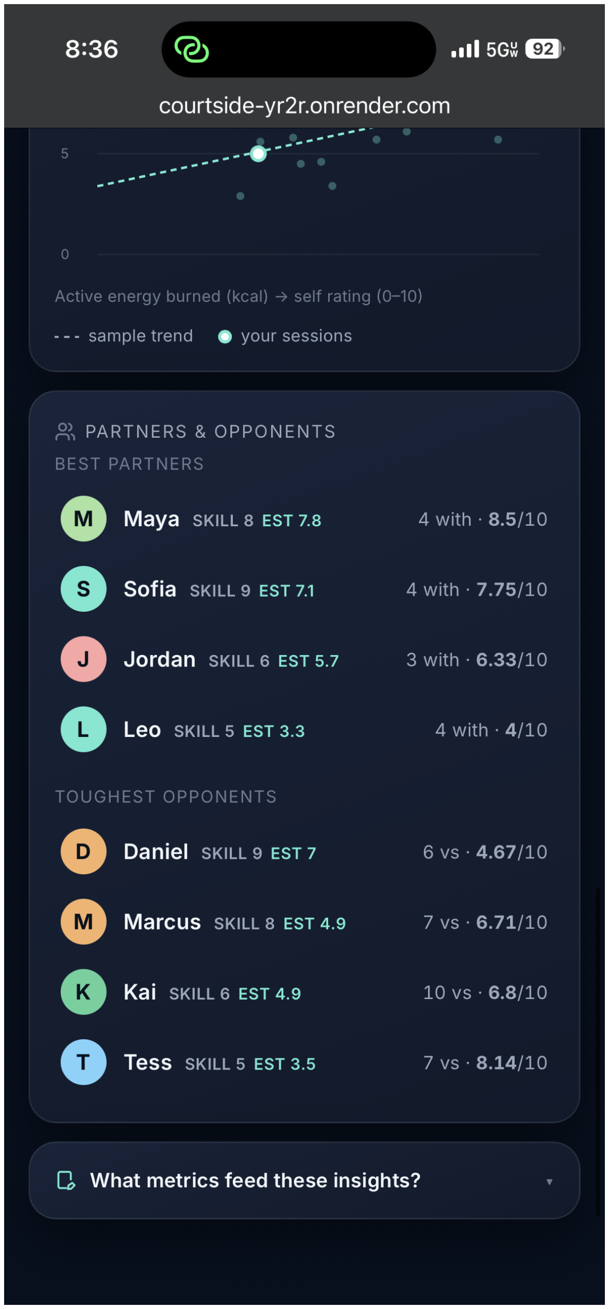
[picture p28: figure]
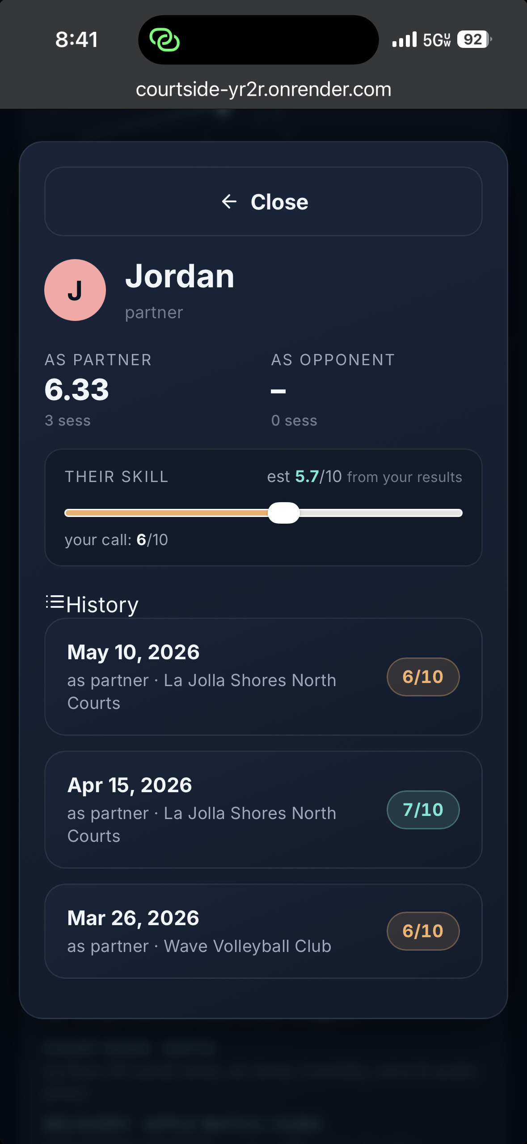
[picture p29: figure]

Figure 7: Relational analytics (sample data; the pilot has only N=2 fully-instrumented real sessions, so these views are demonstrations built around the pilot’s data). Left: relationship signals comparing the athlete’s ratings with/without each person (Welch’s t, small-N guarded)—partner boosts and the “tough matchup” opponent drags. Center: partners and opponents ranked, each with a self-rated and a results-estimated skill. Right: a person view (a partner here) with as-partner/as-opponent averages and full history.

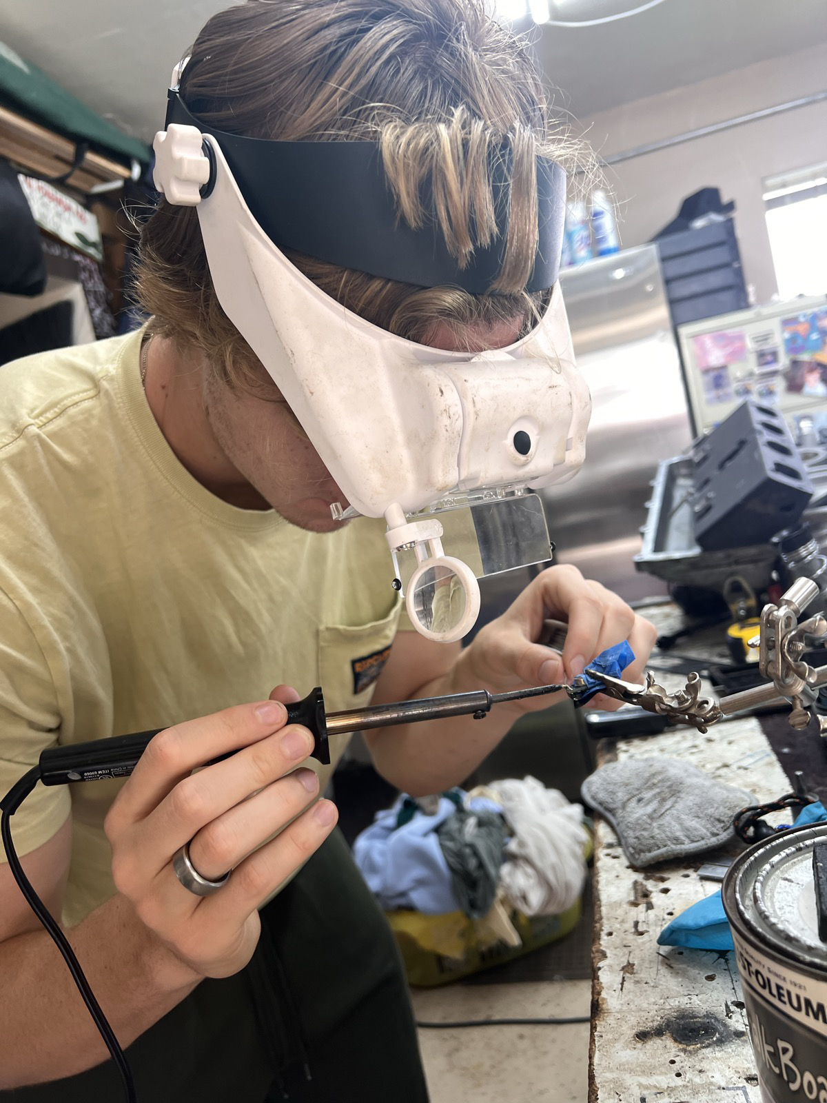
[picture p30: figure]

Figure 8: Fabrication and bring-up. Left: hand-soldering the node under a magnifier visor. Right: the first successful MLX90614 infrared read during bench bring-up.

effort—exactly the contrast the tool is designed to surface, and a reminder that more effort is not more performance.

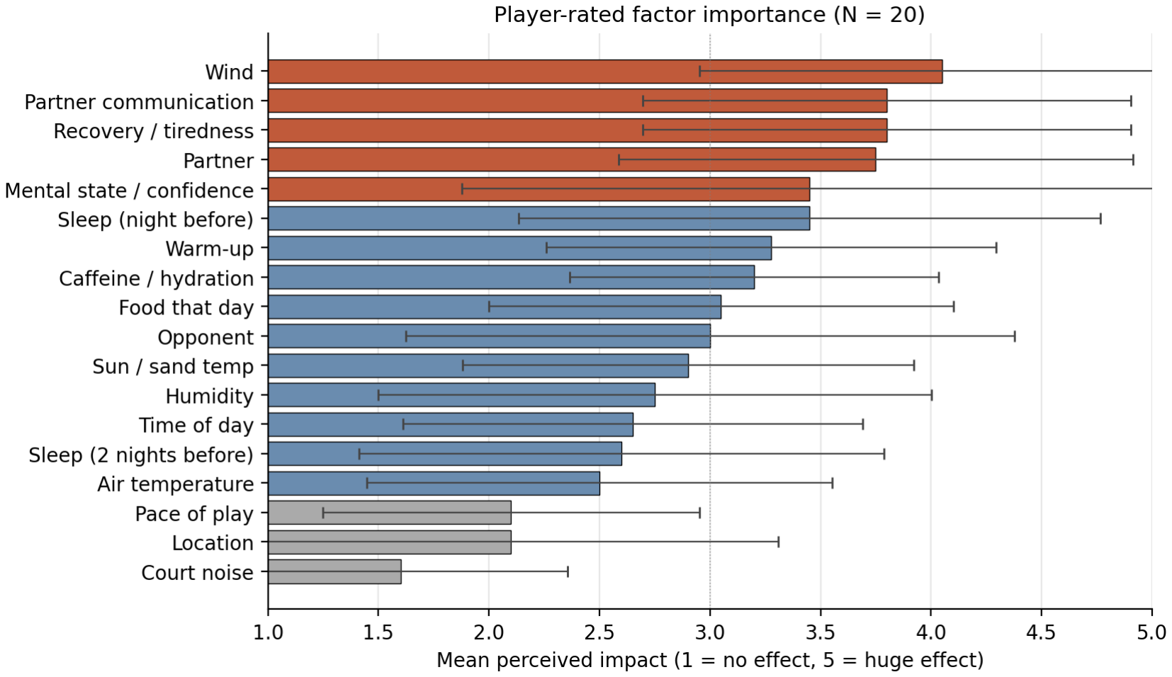
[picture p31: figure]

Figure 9: Player-rated factor importance (N = 20), mean ±

### 1 SD. Wind ranks first overall. Top five (orange) retained as

primary engineered features; bottom three (gray) dropped.

### 8 Discussion

What worked. The hardest integration risks—untethered wireless streaming from a beach, automated wearable ingestion, and time-aligned multi-modal fusion across six streams—are all working

7


Figure 10: Bench validation. Left: an exhalation event produces a coupled temperature/humidity response. Right: the acoustic wind proxy responds to blown-air transients above a stable baseline.


Figure 11: Oura recovery pipeline validated over a rolling multi-week window (HRV, resting HR, sleep), providing an independent cross-check on the Apple Watch recovery stream.

and deployed. The court-level microclimate signal (∼40 ◦C sand vs. ∼26 ◦C air) is real and is precisely the value a single wearable or weather app misses.
Where the value lies. Given the sample size, we are explicit that the contribution is not statistical. The value of this project is
(i) the technology—a genuinely working, deployed, multi-modal instrument; (ii) the user-needs study that grounds it; (iii) filling a real gap no existing tool addresses; and (iv) an extensible platform with clear potential. We make no inferential claims on the real data. Honest limitations. Small N is the dominant limitation: factor ranking on the two fully-instrumented sessions to date is not interpretable, so all real output is framed descriptively and the pipeline reports its own instability. Wind sensing is fundamentally hard with this hardware: estimating true wind speed from a single small microphone behind a port is essentially not possible—a credible anemometric estimate would need a higher-quality sensor and likely several of them. The current proxy is therefore qualitative, validated against self-reported wind and regional weather rather than against a calibrated anemometer, and more field validation is needed. Sensor placement is fixed within the enclosure: the whole node can be rotated to face the wind correctly, but doing so also re-aims the IR sensor, a coupling a future revision should decouple. Sensor fidelity: the DHT11 is low-resolution (±2

◦C, ±5% RH,
no pressure). Ground truth: the subjective 1–10 rating is the primary outcome; kills/errors are secondary and heavily confounded by partner and opponent in 2v2 play, which is exactly why we added peer/coach ratings and the relational analytics rather than over-trusting raw counts.


Figure 12: The Summary recovery panel with real pilot wearable data: HRV (SDNN), resting HR, sleep, the in-session heart rate from a timestamp-paired Volleyball workout (avg 172, max 186 bpm), and active energy—flowing automatically from the Apple Watch into the deployed app.

Scope cuts (and the roadmap). Two stretch goals were deliberately cut to keep the core robust, and both are planned as I continue this as a personal project. Computer-vision performance metrics— automated kills, digs, reach, vertical jump, and score tracking—are feasible with existing technology and mainly need integration. Voice EMA / partner-communication capture would lower in-session reporting burden. Neither was essential to proving the instrument. Reviewer feedback addressed. Per TA and classmate feedback: the report is structured with clearly-marked sections and judicious, high-resolution figures; the survey is elevated as user-need validation; the kills/errors confound is reframed with peer/coach ground truth and relational context; an evaluation section reports what is measurable at current N plus a concrete plan; and the analysis is a committed, specified four-stage pipeline.
Generalization. The patterns—time-aligning heterogeneous low-cost streams, capturing microclimate that regional data misses, small-N feature ranking with honest stability reporting, and spatial/relational context—transfer to other outdoor, individually-variable, heat-exposed settings (e.g., heat-exposed workers).

8


Figure 13: Pipeline factor-ranking output on a labeled sample 16-session dataset built around the pilot’s N=2 real sessions (not real results). Demonstrates the end-to-end analysis and its self-reported stability; real-data ranking awaits sufficient

N.


Figure 14: Relationship views the instrument produces from paired streams (sample data built around the pilot’s N=2 real sessions): actual effort (watch in-session HR, timestampmatched to the node session) vs. self-rated performance (left), and sleep vs. performance (right). Shown to illustrate the analysis; not a real-data finding.

### 9 Conclusion

We delivered a working, deployed multi-modal instrument and analysis pipeline that fuses court-level environmental sensing, wearable recovery and in-session intensity, regional weather, spatial (court) and relational (partner/opponent) context, and subjective performance for an individual beach volleyball athlete—grounded in a 20-player needs survey and validated end-to-end on a live beach pilot. The main takeaway: the integration is real and the court microclimate it captures is genuinely invisible to existing tools; the honest gap is sample size, and because the instrument now collects all streams at near-zero marginal effort, the remaining work—reaching enough sessions and re-running the already-built ranking—is straightforward. We present sample-data output (built around the pilot’s N=2 real sessions) to show what the system produces at scale, and we make no statistical claims on the small real sample.

### AI Use Disclosure

AI tools (Claude) were used as a pair-programming and drafting assistant for the firmware, backend, and web-app code, for editing this report’s prose, and to summarize open-ended survey responses. All system design, hardware integration, data-collection methodology, analysis choices, and the underlying data are the author’s own.

### References

[1] D. J. Casa et al. National Athletic Trainers’ Association position statement: exertional heat illnesses. Journal of Athletic Training, 2015.
[2] S. Shiffman, A. A. Stone, and M. R. Hufford. Ecological momentary assessment. Annual Review of Clinical Psychology, 4:1–32, 2008.
[3] S. M. Lundberg and S.-I. Lee. A unified approach to interpreting model predictions. Advances in Neural Information Processing Systems (NeurIPS), 2017.
[4] F. Pedregosa et al. Scikit-learn: machine learning in Python. Journal of Machine Learning Research, 12:2825–2830, 2011.
[5] Open-Meteo. Free open-source weather API. https://open-meteo.com, accessed 2026.
[6] A. Marzano-Felisatti et al. Electronic performance-tracking of physical-conditional performance in young male beach volleyball players. 2024.
[7] University of Sussex. Wearables in Beach Volleyball project. Accessed 2026.

9

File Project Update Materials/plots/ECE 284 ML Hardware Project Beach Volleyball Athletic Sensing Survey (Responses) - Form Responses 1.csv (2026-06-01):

Timestamp | What level do you play at? | How long have you been playing | Are you a blocker or defender | If you have a CBVA rating what is it? | Rate your current beach volleyball skill on a 1–10 scale: 1 = just picked up the sport 3 = comfortable with fundamentals (pass, set, hit) 5 = solid recreational / club player 7 = competitive tournament player 10 = professional / AVP level | Rate how much each of these affects how you play day-to-day: (1 = no effect, 5 = huge effect) [Sleep quality the night before] | Rate how much each of these affects how you play day-to-day: (1 = no effect, 5 = huge effect) [Sleep quality TWO nights before] | Rate how much each of these affects how you play day-to-day: (1 = no effect, 5 = huge effect) [Time of day played] | Rate how much each of these affects how you play day-to-day: (1 = no effect, 5 = huge effect) [Overall recovery / how tired you feel] | Rate how much each of these affects how you play day-to-day: (1 = no effect, 5 = huge effect) [Air temperature] | Rate how much each of these affects how you play day-to-day: (1 = no effect, 5 = huge effect) [Sun exposure / sand temperature] | Rate how much each of these affects how you play
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

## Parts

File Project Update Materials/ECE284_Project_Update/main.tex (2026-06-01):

\documentclass[sigconf,nonacm]{acmart}

% If acmart unavailable on Overleaf, replace with:
% \documentclass[10pt,twocolumn]{article} and drop the \affiliation block

\settopmatter{printacmref=false, printfolios=false}
\renewcommand\footnotetextcopyrightpermission[1]{}
\pagestyle{plain}

\usepackage{graphicx}
\usepackage{booktabs}
\usepackage{hyperref}
\usepackage{wrapfig}

\setlength{\textfloatsep}{8pt plus 2pt minus 2pt}
\setlength{\intextsep}{8pt plus 2pt minus 2pt}

\title{Project Update: Multi-Modal Performance Sensing for Beach Volleyball Athletes}

\author{Tristan Cooper}
\affiliation{%
  \institution{UC San Diego}
  \city{La Jolla}
  \state{CA}
  \country{USA}
}
\email{tmcooper@ucsd.edu}

\begin{document}
\maketitle

%===================================================================
\section{Problem and Scope Refinement}
%===================================================================

This project builds a multi-modal sensing pipeline that fuses wearable physiology, courtside environmental measurements, and a subjective self-rating to produce per-session factor rankings explaining individual beach volleyball performance variability. Three feedback loops have refined the scope: TA review, three classmate reviews, and a 20-respondent player survey. Two pivots resulted, both directly responsive to TA feedback. \textbf{First}, the subjective 1--10 self-rating has been elevated to the primary outcome; the CV-derived kill/error differential remains in scope but is flagged for demotion to stretch if BalltimeAI access cannot be secured, with the kills/errors-influenced-by-partner-and-opponent limitation to be discussed in the final report. \textbf{Second}, the survey of N=20 players (Section~4) directly informed which contextual features to retain and which to drop, addressing the TA's recommendation to validate user need before further hardware investment.

\begin{figure*}[t]
    \centering
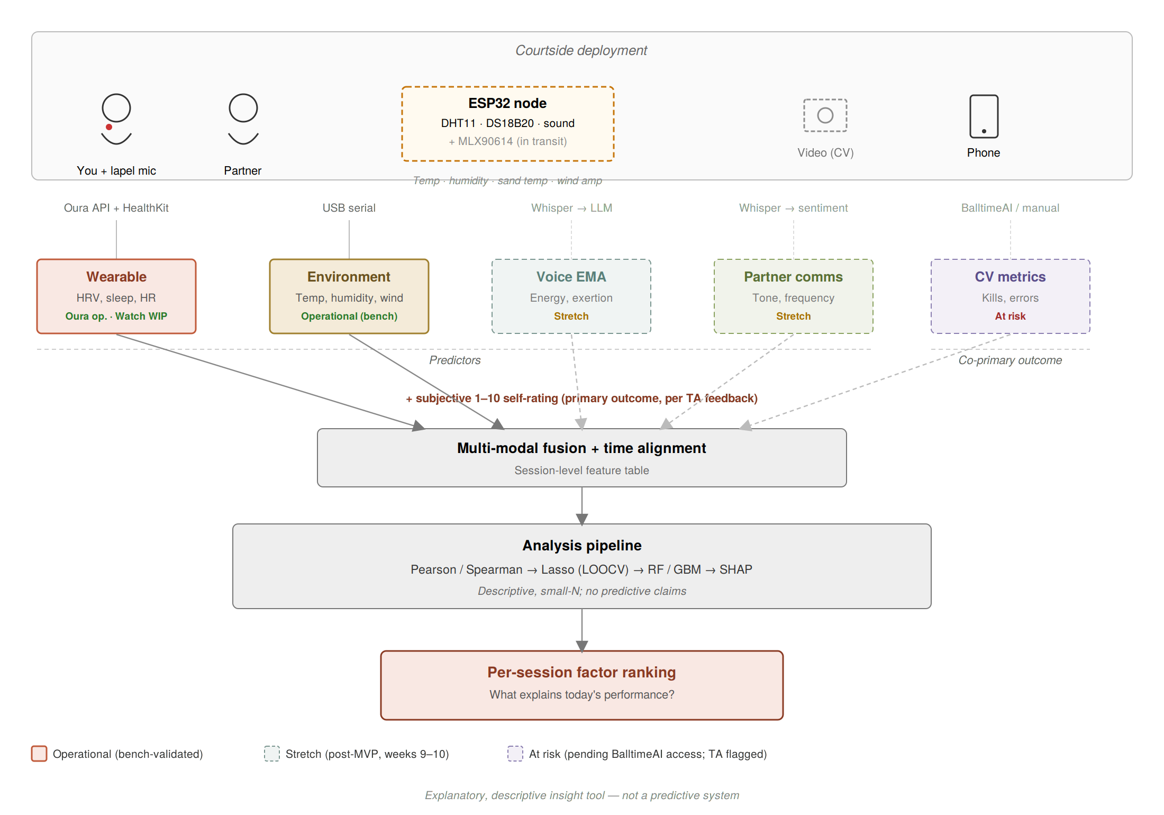
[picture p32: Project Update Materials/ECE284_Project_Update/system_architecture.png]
    
    \caption{System architecture, annotated with implementation status. Wearable (Oura operational, Apple Watch in progress) and environmental (DHT11 + DS18B20 + sound, MLX90614 in transit) streams are bench-validated. Voice EMA and partner communication are scoped as stretch. The CV outcome is flagged ``at risk'' pending BalltimeAI access per TA feedback on ground-truth quality; the subjective 1--10 self-rating is now the primary outcome.}
    \label{fig:arch}
\end{figure*}

%===================================================================
\section{Hardware Progress}
%===================================================================

The courtside node is built on a Lonely Binary ESP32-S3 with external WiFi antenna. It reads three channels at 0.5~Hz: a DHT11 for ambient temperature and humidity, an analog sound sensor for wind-amplitude estimation, and a DS18B20 waterproof probe as an interim contact-based sand-temperature sensor. An MLX90614 IR thermometer is in transit and will replace the DS18B20 on arrival for non-contact sand-surface measurement. The sound-based wind estimation uses windowed mean-absolute-deviation of the microphone signal as a low-cost intensity proxy; a planned upgrade to an I2S MEMS microphone will be evaluated for better low-frequency response, since wind energy concentrates below 200~Hz and the analog module low-passes aggressively. Anemometer ground truth is acknowledged as a stretch requirement and limitation.

Figure~\ref{fig:hardware} shows the assembled node and a representative bench trace generated by exhaling on the sensor at midpoint, producing the expected coupled spike in temperature ($+0.7^\circ$C) and humidity ($+24\%$ RH) followed by exponential return to ambient --- confirming sensor responsiveness and time-alignment of streams.

\begin{figure}[t]
    \centering
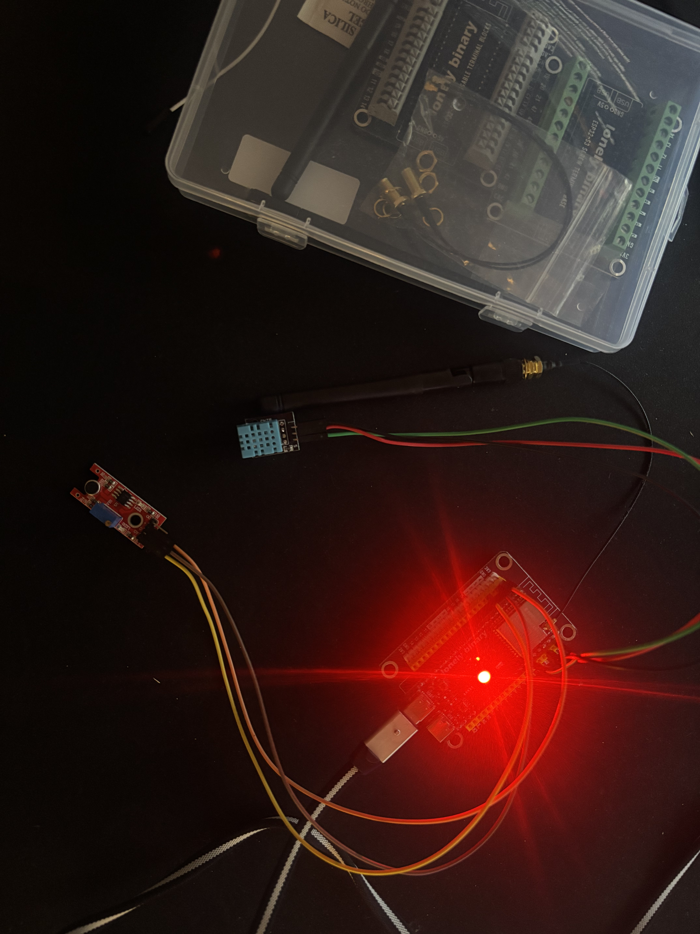
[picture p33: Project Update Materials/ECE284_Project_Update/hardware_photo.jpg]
    
    \hfill
    
    \caption{Left: assembled ESP32-S3 environmental node with DHT11, sound sensor, and DS18B20 probe. Right: live bench-validation trace with operator exhalation event near $t \approx 14.1$~min producing coupled temperature and humidity response.}
    \label{fig:hardware}
\end{figure}

\begin{figure}[!htbp]
    \centering
    
    \caption{First-test validation of the acoustic wind proxy: windowed mean-absolute-deviation of the analog microphone signal. Two large transient spikes near $t = 319$~s and $t = 325$~s are operator-induced (blowing directly on the sensor) and confirm responsiveness; bench ambient baseline is $\sim$15. Quantitative wind-speed calibration against an anemometer remains a stretch goal.}
    \label{fig:wind}
\end{figure}

%===================================================================
\section{Software and Data Pipeline}
%===================================================================

The pipeline is organized as a session-keyed folder structure with one CSV per modality, consolidated downstream into a unified session-level feature table. The ESP32 streams CSV lines over USB serial to a Python bridge that performs live plotting and disk logging in a single pass. Oura integration is complete: a Python client using the v2 personal-access-token API pulls a rolling 21-day window across five endpoints (daily sleep, daily readiness, daily activity, sleep periods, workouts) and writes one normalized CSV per endpoint. Apple Watch via HealthKit export is scoped, not yet implemented; the workflow is a weekly manual export from the iPhone Health app followed by XML parsing of in-session heart rate. Live syncing and a mobile app are explicitly out of scope for this N=1 study --- a researcher-operated workflow is sufficient. Analysis lives in a single Jupyter notebook running the committed pipeline: Pearson/Spearman associations $\to$ Lasso with LOOCV $\to$ random forest and gradient boosting $\to$ SHAP for per-session factor rankings.

\begin{figure}[t]
    \centering
    
    \caption{Oura API pipeline validation: 21-day rolling window of daily sleep, readiness, and activity scores pulled live and normalized to CSV. Activity score reads consistently low because the ring is removed during workouts; the corresponding in-workout activity signal will be filled by the Apple Watch HealthKit pipeline once integrated.}
    \label{fig:oura}
\end{figure}
%===================================================================
\section{User Validation: Player Survey (N = 20)}
%===================================================================

Aggregating responses took longer than anticipated, but the resulting N=20 sample\footnote{Survey link: \url{https://forms.gle/DcEuomBF2MLz8gTh7}} is substantial and reshaped the feature set. Responses came from the UCSD men's and women's beach volleyball teams plus recreational, club, intramural, NCAA, and Open/AVP players outside UCSD; cohort breakdown is shown in Figure~\ref{fig:cohort}. Self-rated skill spanned 1--8 (mean 5.7) on a 10-point scale.

\begin{figure*}[!htbp]
    \centering
    
    \caption{Survey cohort composition and current wearable adoption (N=20). Apple Watch leads existing wearable use (6 of 20), confirming the lead-with-HealthKit decision; Oura and Whoop tie at 2 each.}
    \label{fig:cohort}
\end{figure*}

\begin{figure*}[!htbp]
    \centering
    
    \caption{Player-rated factor importance from the N=20 survey, ordered by mean. Error bars are $\pm 1$ standard deviation. Top five (orange) are retained as primary engineered features; bottom three (gray) have been dropped.}
    \label{fig:survey}
\end{figure*}

Figure~\ref{fig:survey} reports mean perceived importance across 18 candidate factors. The top five (wind, partner communication, recovery/tiredness, partner identity, mental state) all averaged above 3.4/5; three of the five are directly sensable by the current MVP stack. The bottom three (court noise, location, pace of play) all averaged below 2.2/5 and have been dropped from the feature plan. Critically, \textbf{wind ranked first overall} (4.05/5), validating the hardware decision to prioritize wind sensing despite its complexity. Across the cohort, 85\% indicated positive interest in the proposed tool (15\% ``yes, definitely''; 70\% ``maybe, depends on how it works''), with qualified interest concentrated on integration with existing wearables and minimization of in-session burden.

\subsection{Synthesized Player Written Feedback (AI-summarized)}

Open-ended responses surfaced themes not captured in structured ratings. \textbf{Food timing} was the most volunteered factor, with multiple respondents describing large performance swings tied to whether and what they ate in the hour before playing. \textbf{Injury and accumulated soreness} were raised by competitive-level respondents as day-of body-feel distinct from long-term injury status. \textbf{Warm-up quality} appeared independently of the structured rating, suggesting the pre-session ritual may be a useful feature distinct from overall recovery. \textbf{Time-since-last-played} and \textbf{partner attitude/opponent gender} appeared in several responses as factors not anticipated in the original feature list. Qualified ``maybe'' responses converged on three concerns: integration with existing wearables, near-zero in-session burden, and a value proposition centered on controllable factors (sleep, hydration, food) rather than uncontrollable ones (wind, opponent). Two respondents cautioned that over-tracking could cause overthinking --- a useful constraint for any future deployed UI. \emph{This subsection's prose was generated by an AI assistant (Claude) from raw open-ended responses; structured ratings above were unedited.}

%===================================================================
\section{Remaining Goals and Blockers}
%===================================================================

\textbf{This week:} first instrumented data collection at team practice Friday, partner consent finalized, MLX90614 integration on arrival. \textbf{Weeks 8--9:} ramp to two sessions per week, lock the dataset after $\geq 6$ sessions, run the full analysis pipeline, implement HealthKit export. \textbf{Stretch (Weeks 9--10):} voice EMA via Whisper+LLM, partner communication sentiment, MEMS-microphone wind upgrade with anemometer calibration, CV outcome via BalltimeAI. \textbf{Blockers:} the collegiate beach season ended before hardware was operational, pushing first session to Friday; IR sensor lead time delayed sand-temperature integration (DS18B20 closes the gap); BalltimeAI access remains uncertain (\textit{attempting to get free access from my USAVB coach} - CV outcome will be dropped with a limitation paragraph if unresolved by Week 8, per TA feedback). Project is on track for the Week 10 final deliverable.

%===================================================================
\section{AI Use Disclosure}
%===================================================================

AI tools (Claude) were used to (1) generate the prose summary of open-ended survey responses in Section 4.1, as disclosed inline; (2) refine body prose; and (3) render Figure~\ref{fig:arch} from the author's design sketch. All hardware integration, data collection methodology, statistical analysis choices, code, and underlying survey response data are the author's own.\\

\textit{Note exceeded 2 page limit due to many figures included.}

\end{document}

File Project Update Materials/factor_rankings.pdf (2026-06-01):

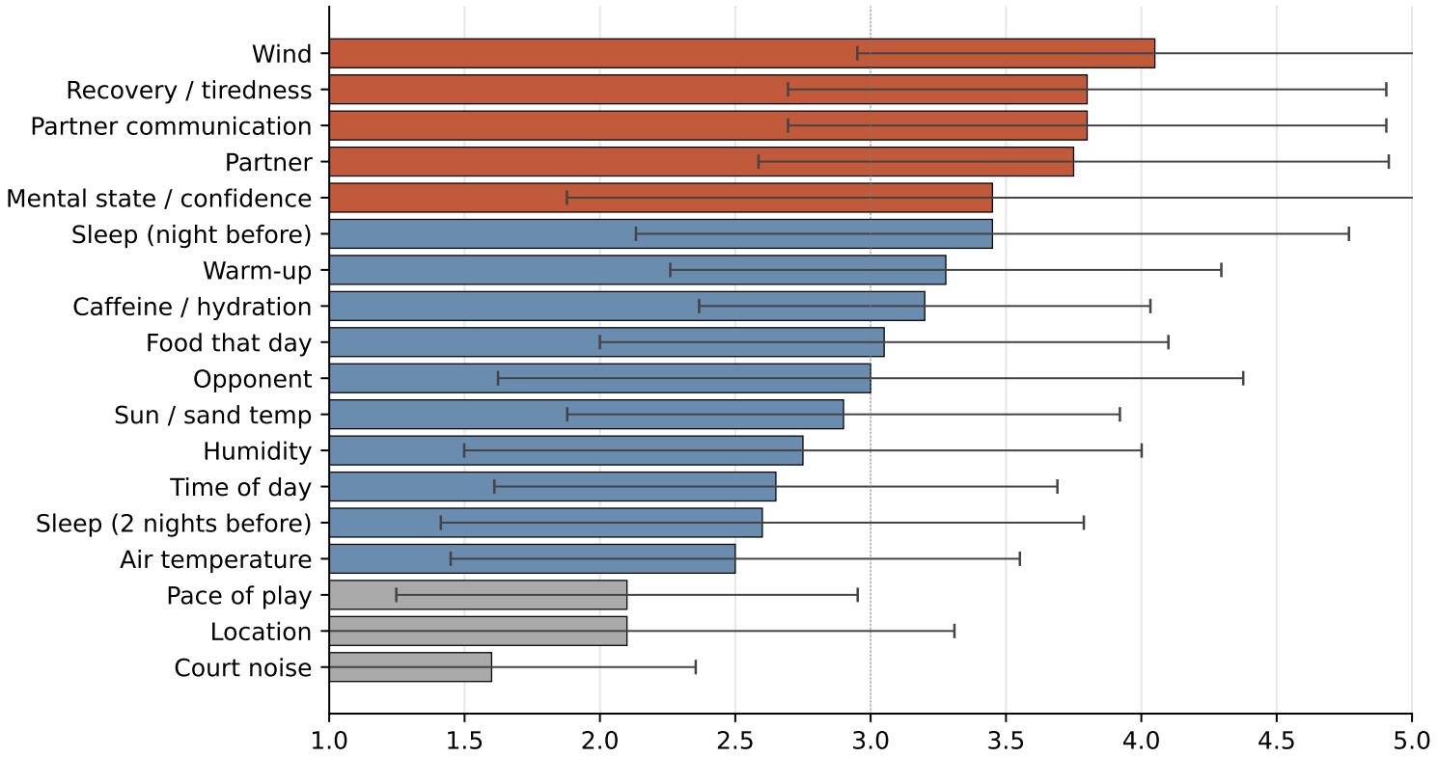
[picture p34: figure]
Court noise; Location; Pace of play; Air temperature; Sleep (2 nights before); Time of day; Humidity; Sun / sand temp; Opponent; Food that day; Caffeine / hydration; Warm-up; Sleep (night before); Mental state / confidence; Partner; Partner communication; Recovery / tiredness; Wind

Mean perceived impact (1 = no effect, 5 = huge effect)

Player-rated factor importance (N = 20)

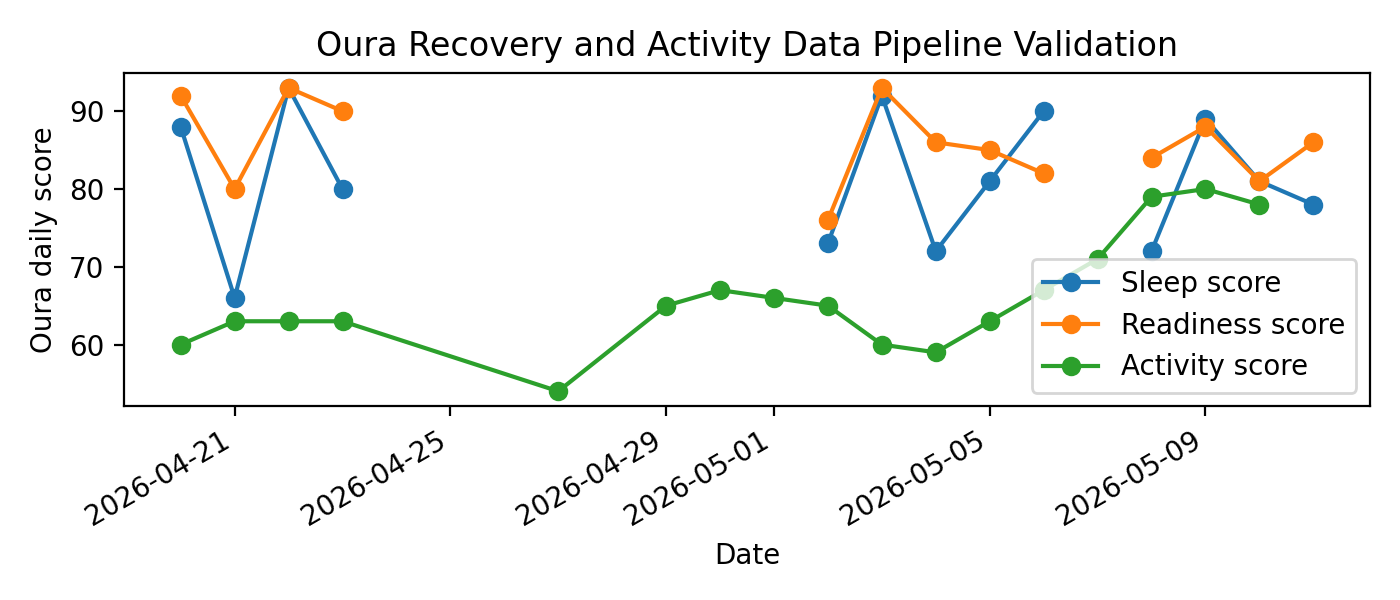
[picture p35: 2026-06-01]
Project Update Materials/plots/oura_daily_scores.png

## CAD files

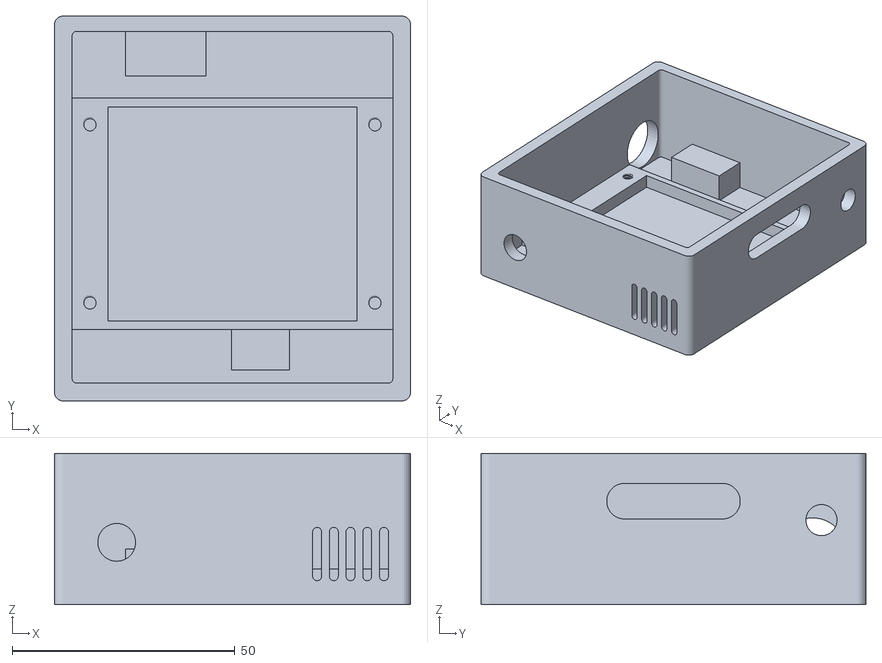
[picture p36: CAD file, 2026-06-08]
CAD designs/Tristan Project.stl
80.0 x 86.4 x 34.0

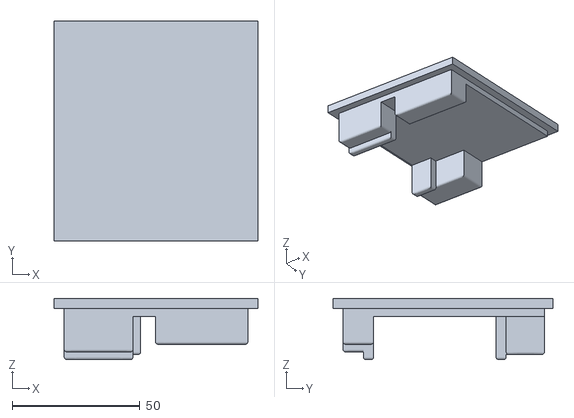
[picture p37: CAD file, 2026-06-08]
CAD designs/Tristan ProjectTop.stl
80.0 x 86.4 x 24.0

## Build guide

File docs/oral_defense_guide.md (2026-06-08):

# Courtside — Oral Defense Study Guide

Everything you need to explain and defend the project. Read top-to-bottom once,
then drill the **Q&A** section.

---

## 1. The 30-second pitch
> "Beach volleyball performance varies a lot day to day, and no single tool
> explains why — wearables only see overnight recovery, weather apps miss the
> court's microclimate, and you can't fill out surveys mid-match. **Courtside** is
> a multi-modal instrument I built and deployed that fuses four streams — a custom
> courtside sensor node, wearable recovery data, regional weather, and my own
> session ratings — into one per-session table, then runs a factor-ranking
> analysis to surface *what likely explained how I played*. It's a working,
> deployed system validated on a small personal pilot; I'm honest that the sample
> is too small for statistical claims yet."

**The one-line product promise:** *"How did I play, what were the conditions, how
was my body, and what probably mattered?"*

---

## 2. Problem → Gap → Contribution
- **Problem:** recovery, environment, and mindset interact, but existing tools each
  measure one dimension alone.
- **Three blind spots:** wearables ignore same-day environment/subjective state;
  weather apps are city-grid (miss court microclimate — wind reshaped by terrain,
  sand temp driven by sun/grain/moisture); in-match self-report is impractical.
- **Gap:** no system *fuses* recovery + environment + subjective state + performance
  for an individual beach athlete.
- **Contribution:** a working multi-modal **instrument + pipeline** (not a
  finished study) that does this fusion at low cost, plus a needs survey (N=20)
  that validated the design. Methods generalize to other heat-exposed, individually-
  variable settings.

---

## 3. Architecture — be able to draw this
```
[ESP32-S3 node]  --WiFi(hotspot)-->  [Cloud backend: FastAPI + PostgreSQL on Render]
  DHT11 (air T/RH)                         |   ^                         ^
  MLX90614 (sand IR)                       |   |                         |
  electret mic (wind/audio)                v   |                         |
                                   [mobile web app]              [Apple Watch]
                                   live view / record / log     via Health Auto Export
                                                                 [Oura API] [Open-Meteo]
                                            |
                                            v
                          [build_features.py] -> per-session feature table
                                            |
                                            v
                          [analysis.py: 4-stage] -> factor_rankings
```
**Data flow in words:** node samples at 1 Hz → POSTs JSON to the cloud → you open
the app on your phone to see live readings and **record** a session (start/stop
bookmarks the sensor window) → after playing you **log** the rating/outcomes →
Apple Watch + Oura + weather attach by date/time → the pipeline builds one row per
session and ranks factors.

---

## 4. Components & the "why" behind each
**Node (ESP32-S3 + DHT11 + MLX90614 + mic).**
- *DHT11* = air temp + humidity (one-wire, GPIO2). *MLX90614* = **non-contact IR
  thermometer** reading **sand surface** temp (I²C, addr 0x5A) — measures emitted
  infrared, no contact needed. *Mic* = peak-to-peak amplitude as a cheap wind/audio
  proxy (GPIO4, an ADC1 pin so it works with WiFi on).
- *Why ESP32-S3:* cheap, WiFi built-in, enough ADC/I²C. *Why hotspot→cloud:* the
  beach has no WiFi and you didn't want a laptop in the sun, so the node joins your
  iPhone Personal Hotspot and posts to a fixed cloud URL.

**Cloud backend (FastAPI + PostgreSQL, Render).**
- One service ingests node + wearable data and serves the app. Postgres persists
  data; SQLite is used locally. *Why cloud:* fixed URL reachable from any beach with
  cell signal; no laptop dependency; same endpoint serves the node, the watch, and
  the dashboard.

**App (mobile web).** Live setup view (per-sensor plots + a heuristic setup-check),
**recording** (start/stop → captures the session's sensor time-series), and an
**evaluation** form (self-rating, peer/coach, felt-wind, kills/errors, notes, GPS).

**Wearables.** Apple Watch auto-syncs via **Health Auto Export** (HRV, resting HR,
sleep, respiratory rate, workouts). Oura via API as a **second** recovery source.
*Why both:* Apple HRV is **SDNN**, Oura is **RMSSD** — two independent estimates →
cross-validation. Workouts give **in-session HR/intensity** + **prior-7-day load**.

**Weather (Open-Meteo).** Coarse (~1–3 km grid) regional reference, kept *separate*
from on-court sensors. *Why:* lets you show the node captures microclimate the
regional model can't — which is the whole thesis.

---

## 5. The ML pipeline (4 stages) — explain each
Outcome = subjective 1–10 self-rating (primary). For each candidate feature:
1. **Correlation screen** — Pearson (linear) + Spearman (rank/monotonic) of each
   feature vs the rating. Cheap, first look.
2. **Sparse linear selection** — **Lasso** (L1-penalized regression) with
   **leave-one-out CV** to pick the penalty. Lasso zeroes out weak features →
   sparse, appropriate for small N. LOOCV because every data point counts when N is tiny.
3. **Nonlinear importance** — **Random Forest + Gradient Boosting** feature
   importances to catch interactions a linear model misses.
4. **SHAP** — Shapley values from the gradient-boosting model: a game-theory method
   attributing each prediction to each feature → per-factor importance + direction.
- Plus **leave-one-session-out stability**: refit dropping each session, see if the
  top-3 factors stay stable. **No p-values as confirmatory. No deployed model.**

---

## 6. The data you actually have (pilot)
- First instrumented beach day: **2 recorded sessions**, ~1,380 and ~2,255 one-Hz
  samples, **sand 40–43 °C vs air ~26 °C** (the microclimate gap, live).
- Apple Watch recovery (HRV/RHR) auto-arrived for the window.
- Survey: **N=20** players; **wind ranked #1** (4.05/5); 85% interested.

---

## 7. Key design decisions & trade-offs (examiners love these)
| Decision | Why | Honest trade-off |
|---|---|---|
| DHT11 (not BME280) | what I had working reliably | low-res (±2°C/±5%RH), no pressure |
| Acoustic mic as wind proxy | cheap, no extra hardware | qualitative only, not a calibrated anemometer |
| Cloud (not SD card / laptop) | no laptop in sun; fixed URL anywhere | depends on cell signal; free-tier cold starts |
| Apple Watch via Health Auto Export | automated, no iOS dev | runs only when phone unlocked |
| Subjective rating = primary outcome | reliable, low-burden, valid in sport psych | subjective |
| Kills/errors = secondary | objective | **confounded by partner & opponent in 2v2** |
| Oura + Apple both | cross-validate HRV (RMSSD vs SDNN) | two devices |

---

## 8. Limitations (lead with these — it's a strength to be honest)
1. **Small N is the dominant limitation.** A factor ranking on ~2–4 sessions is not
   statistically interpretable (a 4-point correlation can exceed 0.8 by chance).
   Everything is framed descriptively; the pipeline reports its own instability.
2. **Ground truth:** kills/errors are partner/opponent-confounded → added optional
   **peer/coach ratings** as better external truth; per-own-contact stats = future.
3. **Sensor fidelity:** DHT11 low-res; mic uncalibrated; weather coarse (by design).
4. **Scope cuts:** voice EMA and CV kill/error extraction were de-scoped to keep the
   core instrument robust.

---

## 9. Validation / evaluation (what you CAN claim)
- **Sensor responsiveness (bench):** breath → coupled temp/humidity spike; blow →
  mic transient; IR jumps ~10 °C aimed at skin.
- **End-to-end pipeline runs** on real pilot data → 42-column fused table.
- **Need validation:** N=20 survey shaped the feature set.
- Evaluation *criteria* (data completeness, time alignment, ranking stability, face
  validity) are defined; stability/face-validity need ≥15 sessions to be meaningful.

---

## 10. Anticipated questions + crisp answers
**Q: With N so small, what can you actually conclude?**
A: Nothing statistically — and I say so. The deliverable is the working instrument
and pipeline; the factor ranking is its *output format*, shown to demonstrate the
analysis runs and self-reports instability. Real conclusions need ~15+ sessions,
which the system now collects at near-zero marginal effort.

**Q: Kills/errors depend on your partner — how is that a valid outcome?**
A: Correct, that's why the **subjective 1–10 is the primary outcome** and kills/
errors are secondary/exploratory. I added **peer and coach ratings** as
less-confounded external ground truth, and splitting stats by my own contacts is
future work. (This is exactly the TA's feedback, addressed.)

**Q: Your mic isn't an anemometer — is the wind data meaningful?**
A: It's a *qualitative* wind/audio proxy, not calibrated wind speed. I validate it
two ways: against my **felt-wind** rating and against **Open-Meteo** regional wind.
A true anemometer is the obvious hardware upgrade.

**Q: Why measure sand temp — isn't air temp enough?**
A: No — surface temp diverged from air by ~15 °C in the pilot (40 vs 26). Sand temp
drives foot comfort, push-off, and heat load, and weather/air data can't see it.
It's the novel, hard-to-get signal.

**Q: SHAP/Lasso on 4 points — isn't that overfitting?**
A: Yes, which is why it's labeled exploratory and paired with leave-one-out
stability. The methods are the *pipeline*; they become valid at higher N.

**Q: How do you align streams in time?**
A: Sensor rows carry server-receive timestamps; a session has an explicit
start/stop recording window; wearable data joins by date; workouts by time overlap.

**Q: Apple SDNN vs Oura RMSSD — why both / are they comparable?**
A: Both estimate HRV but with different math (SDNN = SD of all RR intervals; RMSSD =
short-term beat-to-beat). They're correlated but not identical — having both lets me
cross-check and fill gaps; I never average them blindly.

**Q: How is missing data handled?**
A: Pipeline imputes feature means for models, drops all-NaN/constant features, and
skips model stages entirely below the sample threshold.

**Q: Privacy / why a web app, not native?**
A: Health data lives in a private repo + private backend; secrets are gitignored. A
web app avoids the App Store and works cross-device; native HealthKit would need an
iOS app I didn't have time/justification to build.

**Q: What's novel vs just using Oura?**
A: Oura tells you your recovery. It can't tell you the sand was 43 °C, the wind was
gusting, and you still rated the session a 7. The fusion + court microclimate is new.

---

## 11. Glossary (say these confidently)
- **HRV / SDNN / RMSSD** — heart-rate variability; SDNN = std-dev of RR intervals
  (Apple), RMSSD = root-mean-square of successive differences (Oura). Higher ≈ more
  recovered/parasympathetic.
- **MLX90614** — non-contact IR thermometer; reads surface temp from emitted infrared.
- **Lasso** — linear regression with L1 penalty; shrinks weak coefficients to zero.
- **LOOCV** — leave-one-out cross-validation; train on N−1, test on 1, repeat.
- **Random Forest / Gradient Boosting** — tree ensembles; capture nonlinear
  interactions; report feature importances.
- **SHAP** — Shapley additive explanations; per-feature contribution to a prediction.
- **Peak-to-peak** — max minus min of the mic signal in a 50 ms window (amplitude).
- **WBGT** — wet-bulb globe temperature; standard heat-stress index in sport.
- **EMA** — ecological momentary assessment (in-the-moment self-report).

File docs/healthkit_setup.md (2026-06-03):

# Apple Watch → Backend (Health Auto Export) setup

Goal: your daily recovery metrics (HRV, resting HR, sleep) upload automatically to
the Courtside backend's `/ingest/health`, landing in the `health_daily` table that
the analysis joins to each session by date. You already have HAE Premium.

> Endpoint = `<BACKEND_URL>/ingest/health`
> - Cloud (recommended): `https://<your-app>.onrender.com/ingest/health`
> - Local test on hotspot: `http://<laptop-ip>:8000/ingest/health`

## Automation 1 — Health Metrics (the important one)
In the Health Auto Export app:
1. **Automations tab → New Automation**.
2. **Automation Type:** REST API.
3. **Name:** `Courtside health`.
4. **URL:** `<BACKEND_URL>/ingest/health`
5. **HTTP Headers:** none required. (Later, if you set a backend `NODE_KEY`, you'd
   add a matching header — skip for now.)
6. **Data Type:** Health Metrics → **Select Health Metrics:**
   - Heart Rate Variability
   - Resting Heart Rate
   - Sleep Analysis
   - Respiratory Rate
   - Heart Rate
7. **Export Format:** JSON
8. **Summarize Data:** ON
9. **Time Grouping:** Days
10. **Batch Requests:** ON
11. **Date Range:** start with **Previous 7 Days** (backfills history); after the
    first run, switch to **Since Last Sync**.
12. **Sync Cadence:** every 1 hour (or daily — these are daily metrics).
13. **Tap Update** to save.

### Test it now
- Tap **Manual Export → pick today (or last 7 days) → Export**.
- **View Activity Logs** in the automation → you want an **HTTP 200** with a summary.
- The backend replies `{"ok":true,"days_written":N,"metrics_seen":[...]}` — that's success.

## Automation 2 — Workouts (optional, for in-session HR)
Make a second REST API automation, same URL, **Data Type: Workouts**, Include
Workout Metrics ON. This carries the heart-rate trace from each Apple Watch
workout you start courtside. (Note: the backend currently stores the daily metrics;
parsing the workout HR trace is a small future add — set this up now so the data
is captured server-side regardless.)

## During a session
Start an Apple Watch **workout** when you start playing (Volleyball or Other) and
stop it when you finish — that's what produces the in-session HR.

## iOS limitations (why a sync might be late)
- Automations only run while the **iPhone is unlocked** (Apple rule). Tip: keep it
  charging / use iPhone Mirroring to let them run more reliably.
- Background App Refresh must be ON for HAE; Low Power Mode delays runs.
- If a day looks missing, open HAE and run a **Manual Export** for that date.

## How it maps into the pipeline
| HAE metric | backend field (`health_daily`) |
|---|---|
| heart_rate_variability | `hrv_sdnn` |
| resting_heart_rate | `resting_hr` |
| sleep_analysis | `sleep_hours` |

Joined to each session by **date**. Oura can backfill the same table
(`source="oura"`) for days before you switched to Apple Watch.

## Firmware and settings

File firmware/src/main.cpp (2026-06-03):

// main.cpp — Courtside node firmware (ESP32-S3-WROOM, "Lonely Binary Gold")
//
// Sensors:
//   - DHT11   : air temp + humidity   (1-wire DATA on GPIO2)
//   - MLX90614: IR sand-surface temp  (I2C, SDA=21 SCL=20, addr 0x5A)
//   - Mic     : sound/wind proxy       (analog, GPIO4 = ADC1)
//
// Always prints one CSV row/sec over Serial @115200 (bench/offline fallback).
// If USE_WIFI (in secrets.h) is 1, it ALSO POSTs each reading as JSON to the
// backend's /ingest/court, which feeds the live web dashboard.
//
// CSV columns: millis,temp_C,humidity_pct,ir_object_C,ir_ambient_C,sound_pp
// (DHT11 has no pressure, so no pressure column.)

#include <Arduino.h>
#include <Wire.h>
#include <Adafruit_Sensor.h>
#include <Adafruit_MLX90614.h>
#include <DHT.h>

#include "secrets.h"          // copy secrets.h.example -> secrets.h, then fill in
#ifndef USE_WIFI
#define USE_WIFI 0

#endif
#if USE_WIFI
#include <WiFi.h>
#include <HTTPClient.h>
#include <WiFiClientSecure.h>
#endif

// ---- DHT11 (one-wire temp/humidity)
#define DHT_PIN  2
#define DHT_TYPE DHT11

// ---- I2C pins for the MLX90614. Match these to your actual wiring.
#define I2C_SDA 21
#define I2C_SCL 20

// ---- Mic: GPIO4 = ADC1_CH3. ADC1 is safe to read while WiFi is active.
#define MIC_PIN 4
#define MIC_WINDOW_MS 50      // window for peak-to-peak amplitude

#define LOG_INTERVAL_MS 1000

DHT dht(DHT_PIN, DHT_TYPE);
Adafruit_MLX90614 mlx = Adafruit_MLX90614();

bool mlxOK = false;
unsigned long lastLog = 0;
float lastTemp = NAN, lastHum = NAN;   // cache last good DHT read (it occasionally NaNs)

float readSoundLevel() {
  unsigned long start = millis();
  int sigMax = 0;
  int sigMin = 4095;
  while (millis() - start < MIC_WINDOW_MS) {
    int s = analogRead(MIC_PIN);
    if (s > sigMax) sigMax = s;
    if (s < sigMin) sigMin = s;
  }
  return (float)(sigMax - sigMin);   // peak-to-peak amplitude (raw ADC units)
}

// Prints every responding I2C address — use this to confirm the MLX90614 (0x5A)
// is on the bus when wiring.
void scanI2C() {
  Serial.println("# I2C scan:");
  uint8_t found = 0;
  for (uint8_t addr = 1; addr < 127; addr++) {
    Wire.beginTransmission(addr);
    if (Wire.endTransmission() == 0) {
      Serial.printf("#   found 0x%02X\n", addr);
      found++;
    }
  }
  if (found == 0) Serial.println("#   (none found — check wiring / pull-ups)");
}

#if USE_WIFI
// JSON-safe number: NaN -> null (the backend's CourtIn fields are all optional).
static String jnum(float v, int dec) { return isnan(v) ? String("null") : String(v, dec); }

void connectWiFi() {
  WiFi.mode(WIFI_STA);
  WiFi.setAutoReconnect(true);
  WiFi.begin(WIFI_SSID, WIFI_PASSWORD);
  Serial.printf("# WiFi: connecting to \"%s\" ", WIFI_SSID);
  unsigned long t0 = millis();
  while (WiFi.status() != WL_CONNECTED && millis() - t0 < 12000) { delay(300); Serial.print("."); }
  if (WiFi.status() == WL_CONNECTED)
    Serial.printf("\n# WiFi: connected (IP %s) -> POSTing to %s\n",
                  WiFi.localIP().toString().c_str(), BACKEND_URL);
  else
    Serial.println("\n# WiFi: NOT connected — running serial-only");
}

void postReading(float t, float h, float irO, float irA, float snd) {
  if (WiFi.status() != WL_CONNECTED) return;

  String body = String("{\"node_id\":\"") + NODE_ID + "\","
              + "\"device_millis\":" + String(millis()) + ","
              + "\"temp_c\":"       + jnum(t, 1)   + ","
              + "\"humidity_pct\":" + jnum(h, 1)   + ","
              + "\"ir_object_c\":"  + jnum(irO, 2) + ","
              + "\"ir_ambient_c\":" + jnum(irA, 2) + ","
              + "\"sound_pp\":"     + jnum(snd, 0) + "}";

  String url = String(BACKEND_URL) + "/ingest/court";
  HTTPClient http;
  http.setConnectTimeout(1500);
  http.setTimeout(1500);

  WiFiClient plain;
  WiFiClientSecure secure;
  bool began;
  if (url.startsWith("https")) { secure.setInsecure(); began = http.begin(secure, url); }
  else                         { began = http.begin(plain, url); }

  if (began) {
    http.addHeader("Content-Type", "application/json");
    http.addHeader("X-Node-Key", NODE_KEY);
    http.POST(body);     // fire-and-forget; ignore the response
    http.end();
  }
}
#endif  // USE_WIFI

void setup() {
  Serial.begin(115200);
  delay(1000);

  dht.begin();
  Wire.begin(I2C_SDA, I2C_SCL);
  analogReadResolution(12);          // 0..4095

  // --- startup config summary (lines starting with # are ignored by the pipeline)
  Serial.printf("# DHT11 configured on GPIO%d\n", DHT_PIN);
  Serial.printf("# MLX90614 I2C configured SDA=%d SCL=%d\n", I2C_SDA, I2C_SCL);
  Serial.printf("# Mic configured on GPIO%d\n", MIC_PIN);

  scanI2C();
  mlxOK = mlx.begin();
  if (!mlxOK) Serial.println("# WARNING: MLX90614 not found (solder the header — see README)");

#if USE_WIFI
  connectWiFi();
#else
  Serial.println("# WiFi disabled (USE_WIFI=0) — serial-only");
#endif

  // CSV header — keep column names stable for the pipeline / backend.
  Serial.println("millis,temp_C,humidity_pct,ir_object_C,ir_ambient_C,sound_pp");
}

void loop() {
  if (millis() - lastLog < LOG_INTERVAL_MS) return;
  lastLog = millis();

  float t = dht.readTemperature();   // °C
  float h = dht.readHumidity();      // %RH
  if (!isnan(t)) lastTemp = t;
  if (!isnan(h)) lastHum = h;

  float irObj = mlxOK ? mlx.readObjectTempC()  : NAN;   // sand surface temp
  float irAmb = mlxOK ? mlx.readAmbientTempC() : NAN;
  float sound = readSoundLevel();

  Serial.print(millis());     Serial.print(",");
  Serial.print(lastTemp, 1);  Serial.print(",");   // DHT11 is ±2°C, 1 decimal is plenty
  Serial.print(lastHum, 1);   Serial.print(",");
  Serial.print(irObj, 2);     Serial.print(",");
  Serial.print(irAmb, 2);     Serial.print(",");
  Serial.println(sound, 0);

#if USE_WIFI
  postReading(lastTemp, lastHum, irObj, irAmb, sound);
#endif
}

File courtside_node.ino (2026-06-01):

#include <Arduino.h>
#include <Wire.h>
#include <Adafruit_Sensor.h>
#include <Adafruit_BME280.h>
#include <Adafruit_MLX90614.h>
#include <DHT.h>

// ---------- Pin setup ----------
#define I2C_SDA 21
#define I2C_SCL 20

#define MIC_PIN 4
#define DHT_PIN 2

// If your one-wire temp/humidity sensor is DHT11, change this to DHT11.
#define DHT_TYPE DHT22

#define MIC_WINDOW_MS 50
#define LOG_INTERVAL_MS 1000

Adafruit_BME280 bme;
Adafruit_MLX90614 mlx = Adafruit_MLX90614();
DHT dht(DHT_PIN, DHT_TYPE);

bool bmeOK = false;
bool mlxOK = false;
bool dhtOK = true;

unsigned long lastLog = 0;

float readSoundLevel() {
  unsigned long start = millis();
  int sigMax = 0;
  int sigMin = 4095;

  while (millis() - start < MIC_WINDOW_MS) {
    int s = analogRead(MIC_PIN);
    if (s > sigMax) sigMax = s;
    if (s < sigMin) sigMin = s;
  }

  return (float)(sigMax - sigMin);
}

void scanI2C() {
  Serial.println("# I2C scan starting...");

  int count = 0;

  for (byte address = 1; address < 127; address++) {
    Wire.beginTransmission(address);
    byte error = Wire.endTransmission();

    if (error == 0) {
      Serial.print("# I2C device found at 0x");
      if (address < 16) Serial.print("0");
      Serial.println(address, HEX);
      count++;
    }
  }

  if (count == 0) {
    Serial.println("# No I2C devices found");
  }

  Serial.println("# I2C scan done");
}

void setup() {
  Serial.begin(115200);
  delay(1500);

  analogReadResolution(12);

  Wire.begin(I2C_SDA, I2C_SCL);
  dht.begin();

  scanI2C();

  bmeOK = bme.begin(0x76) || bme.begin(0x77);
  mlxOK = mlx.begin();

  if (!bmeOK) {
    Serial.println("# WARNING: BME280 not found on I2C");
  }

  if (!mlxOK) {
    Serial.println("# WARNING: MLX90614 not found on I2C");
  }

  Serial.println("millis,dht_temp_C,dht_humidity_pct,bme_temp_C,bme_humidity_pct,bme_pressure_hPa,ir_object_C,ir_ambient_C,sound_pp");
}

void loop() {
  if (millis() - lastLog < LOG_INTERVAL_MS) {
    return;
  }

  lastLog = millis();

  float dhtTemp = dht.readTemperature();
  float dhtHum = dht.readHumidity();

  if (isnan(dhtTemp) || isnan(dhtHum)) {
    dhtTemp = NAN;
    dhtHum = NAN;
  }

  float bmeTemp = bmeOK ? bme.readTemperature() : NAN;
  float bmeHum = bmeOK ? bme.readHumidity() : NAN;
  float bmePress = bmeOK ? bme.readPressure() / 100.0F : NAN;

  float irObj = mlxOK ? mlx.readObjectTempC() : NAN;
  float irAmb = mlxOK ? mlx.readAmbientTempC() : NAN;

  float sound = readSoundLevel();

  Serial.print(millis());
  Serial.print(",");

  Serial.print(dhtTemp, 2);
  Serial.print(",");
  Serial.print(dhtHum, 2);
  Serial.print(",");

  Serial.print(bmeTemp, 2);
  Serial.print(",");
  Serial.print(bmeHum, 2);
  Serial.print(",");
  Serial.print(bmePress, 2);
  Serial.print(",");

  Serial.print(irObj, 2);
  Serial.print(",");
  Serial.print(irAmb, 2);
  Serial.print(",");

  Serial.println(sound, 0);
}

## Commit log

2026-06-01 Initial commit: existing pipeline + repo/PlatformIO scaffolding
    - Add .gitignore, .env.example, requirements.txt, README
    - Add PlatformIO firmware/ (port of courtside_node.ino + I2C scanner)
    - Existing Oura pipeline, survey analysis, ESP32 CSV, write-ups
    [ECE 284 ML Hardware Project Beach Volleyball Athletic Sensing Survey (Responses) - Form Responses 1.csv, sound_live_log.csv]
2026-06-01 Add web app, DHT11 firmware, and weather/validation tooling
    Firmware:
    - Switch temp/humidity from BME280 to DHT11 (GPIO2); MLX90614 IR on I2C
    21/20; mic on GPIO4. Drop pressure column; boot diagnostics + I2C scan.
    Backend (FastAPI + SQLAlchemy):
    - Endpoints: /ingest/court, /ingest/health (Health Auto Export), /api/live,
    /api/court/recent, sessions CRUD.
    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
    [ECE 284 ML Hardware Project Beach Volleyball Athletic Sensing Survey (Responses) - Form Responses 1.csv]
2026-06-03 Add WiFi POST firmware, Render deploy config, and first-session runbook
    - firmware: ESP32 connects to WiFi and POSTs readings to /ingest/court
    (gated by USE_WIFI in secrets.h; NaN -> JSON null; http + https).
    - render.yaml: one-click Render Blueprint (web service + free Postgres).
    - scripts/run_backend.sh: start backend from a stable venv + DB off iCloud.
    - docs/runbook_first_session.md: end-to-end first-collection procedure.
    - gitignore: exclude .claude/ and local *.db / *.sqlite3.
2026-06-03 Add analysis pipeline: /api/export, build_features, 4-stage factor ranking
    - backend: GET /api/export dumps sessions + court readings + health for offline analysis.
    - scripts/build_features.py: pulls /api/export, aggregates court readings per
    session day, joins wearable by date, attaches Open-Meteo weather via lat/lon ->
    features/session_features.csv.
    - scripts/analysis.py: Pearson/Spearman -> Lasso(LOOCV) -> RF/GBM -> SHAP, plus
    leave-one-session-out top-3 stability; small-N safe; 300-dpi output.
    [analysis.py, build_features.py, main.cpp]
2026-06-04 Session recording lifecycle + peer/coach eval + summary; window features by session
    Backend:
    - Session.start/stop endpoints (server-stamped start_ts/end_ts), PATCH (edit),
    DELETE, GET detail (with windowed sensor aggregates), GET /readings, GET /api/summary.
    - Add peer_rating_1_10, coach_rating_1_10 (ground-truth), status fields.
    - ensure_columns(): tiny auto-migration adds new model columns to existing tables.
    Pipeline:
    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
2026-06-04 v2 web app: Record / Sessions / Summary
    - Record tab: live plots for ALL sensors (sand IR, air, humidity, wind) + a
    setup-check banner (warns if IR ~ air temp / sensors offline / mic floating)
    + sand ring + Start/Stop recording flow that bookends the session window.
    - Evaluation form with sliders: self / peer / coach rating, segmented wind,
    kills/errors, partner/opponent/location/geo, felt state, notes.
    - Sessions tab: list -> inspect a session (windowed sensor aggregates) -> edit
    any field / delete.
    - Summary tab: session count, avg/best self rating, rating-over-time chart.
    - Fix start_session id collision for sessions started in the same second.
    - Cache-bust static assets (?v=2).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
2026-06-04 Capture all HAE metrics (lossless raw + respiratory_rate); Oura cross-validation; full-page session detail
    - /ingest/health stores every metric HAE sends in raw JSON (lossless) and adds a
    respiratory_rate column; analysis stays focused but nothing is discarded.
    - build_features: add Oura daily (HRV/resting-HR/sleep/readiness) as oura_* columns
    for cross-validating Apple Watch (read only needed cols to avoid overflow).
    - UI: session detail is now a full-page view with a Back button (clear selection).
    - Cache-bust assets v=3; gitignore generated features/.
    [build_features.py]
2026-06-04 Robust sleep parsing (multi-key + stage sum) and capture full sleep object in raw
2026-06-04 UI redesign: ocean/sand/aqua palette, Lucide icons, human copy, richer cards & insights
    - New palette (deep ocean base, sand accents, aqua for live/healthy; less orange).
    - Lucide-style inline icons (tabs, sensors, logo, actions).
    - Human status copy ("Live · 6s", "Offline · last seen 22h ago"); formatted dates;
    no NULL / raw seconds; sand-temp interpretation pill (Cool/Comfortable/Warm/Hot).
    - Richer session cards (date + conditions + value-colored rating badge); list
    endpoint now returns per-session sensor summary.
    - Sectioned session detail (Conditions / Performance / Context).
    - Summary: trend (improving/declining/steady) + Oura-style condition insights
    (sand/wind vs rating) + re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
2026-06-08 Final report: rewrite proposal -> deployed-system + honest pilot results
    - Reflects what was actually built (ESP32-S3 + DHT11 + MLX90614 + mic, cloud
    FastAPI/Postgres app, Apple Watch + Oura + Open-Meteo ingest, 4-stage pipeline).
    - Survey (N=20) elevated as user-need validation; pilot results (sand 40-43C,
    ~1.4k-2.3k samples/session) reported honestly; small-N stated as the central limit.
    - Addresses TA feedback: kills/errors confound + peer/coach ground truth, 300dpi
    figures, evaluation section + plan, length tightened. Gitignore LaTeX artifacts.
2026-06-08 Add today's beach-deployment photo + enclosure CAD to report; commit visuals + CAD source
    [Tristan Project.stl, Tristan ProjectTop.stl]
2026-06-08 Rebalance Record screen, add workout-paired indicator + player-state fields
    - Record: replace dominant sand hero with a balanced 2x2 grid of equal cards
    (Surface temp, Wind proxy, Air temp, Humidity), each with a live sparkline
    and an interpretation tag (Warm/Windy/etc.) — it reads as a court-conditions
    dashboard, not a sand-temperature dashboard
    - Sessions: aqua workout icon on cards whose window overlaps an Apple Watch
    workout; detail view gains a "workout paired" header indicator
    - Eval form + detail: new Player State section (energy/soreness/mental/warmup
    1-5 + food timing); backend persists these and exposes has_workout on the
    list/detail endpoints (overlap of session wind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
    [analysis.py]
2026-06-08 Final report rewrite + live screenshots, photos, app deep-links
    - Rewrote the ACM 2-column report: added a deep System Architecture &
    Implementation section (node, firmware/connectivity, backend/data model,
    app, map, personas), a dated-less Design Decisions & Development History
    timeline, and sharpened limitations per the author's notes (small N as the
    dominant limit, wind sensing fundamentally hard with one mic, fixed sensor
    placement, CV/voice-EMA scope cuts). Clearly marked sections, references
    added. Compiles cleanly (verified via article fallback; acmart on Overleaf).
    - Added figures: labeled internal-hardware photo (tikz numbered callouts),
    fabrication (soldering + IR smo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
    [seed_demo.py]
2026-06-08 Report: swap in current-UI screenshots, fix CAD figure, state N=2 real
    - Replace the outdated app screenshots (old 3-tab UI) with current-UI captures
    supplied by the author: Record/eval/sessions (4-tab nav, real 40C-sand June
    sessions with workout icons), Map with an open court popup, relationship
    signals, people ranking, partner person-view, and a recovery panel showing
    real Apple Watch data. Removed superseded/unreferenced figures.
    - Fix the node-in-sand + CAD figure so both fit side by side (balanced widths).
    - State explicitly that the pilot has only N=2 fully-instrumented real sessions,
    next to every mention of the demonstrated/sample analytics, and that the
    sample dataset i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
